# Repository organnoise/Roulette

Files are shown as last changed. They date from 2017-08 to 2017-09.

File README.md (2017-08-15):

# Roulette

<p align="center">
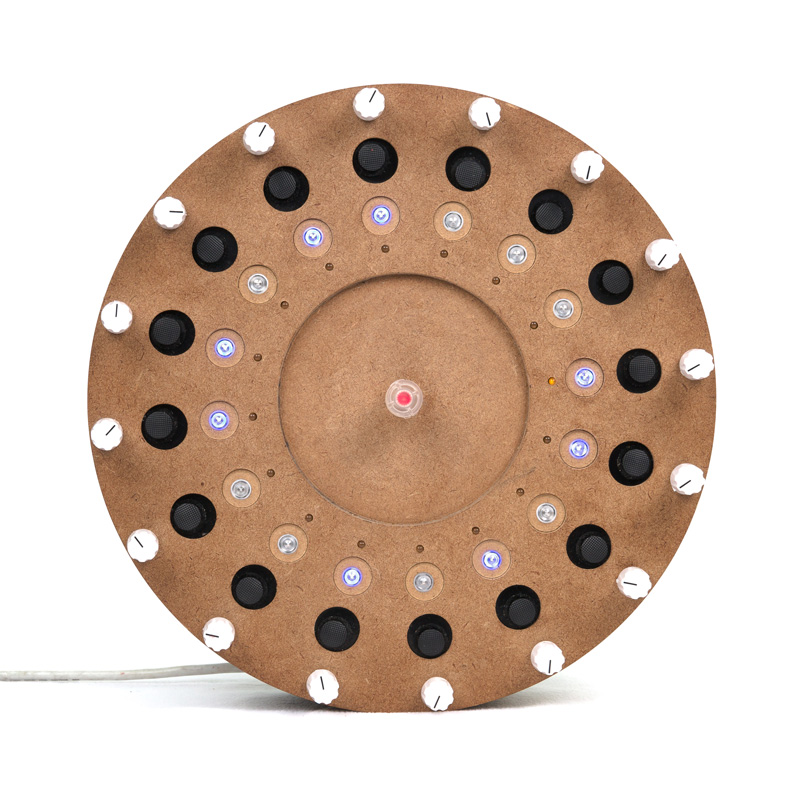
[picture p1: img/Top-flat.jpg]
  
</p>

Roulette is a generative sequencer that uses probability algorithms to create rhythmically varied drum patterns. Compositionally the intent of Roulette is to enable its user to program drum patterns in a dynamic fashion, as opposed to the static nature of typical sequential composition. From the initial design of a rhythm, varied patterns are emitted outlining a principal musical form

## CAD
CAD files for 3D printing and CNC-ing

## Arduino 
Arduino code for Teeny++ 2.0

## Eagle

Designs for both the module and the shield pcbs.

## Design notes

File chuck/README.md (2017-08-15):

# Chuck Code
<p align="center">
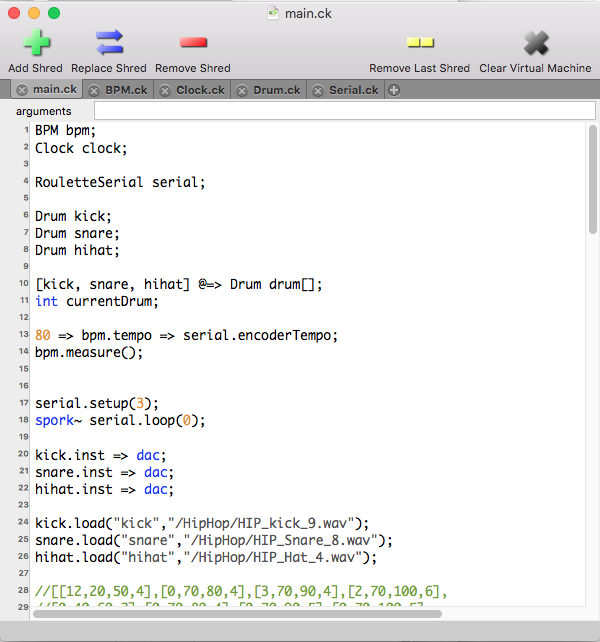
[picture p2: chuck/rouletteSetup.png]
  
</p>

Add all classes in picture above, most use BPM as a dependency so add that first.

```main.ck``` is an example of how to use the chuck code, specifically the ```Drum.ck``` class. 

## Drum.ck
```load(string OSCSendName,string pathToAudio)```

```play(float volume)```

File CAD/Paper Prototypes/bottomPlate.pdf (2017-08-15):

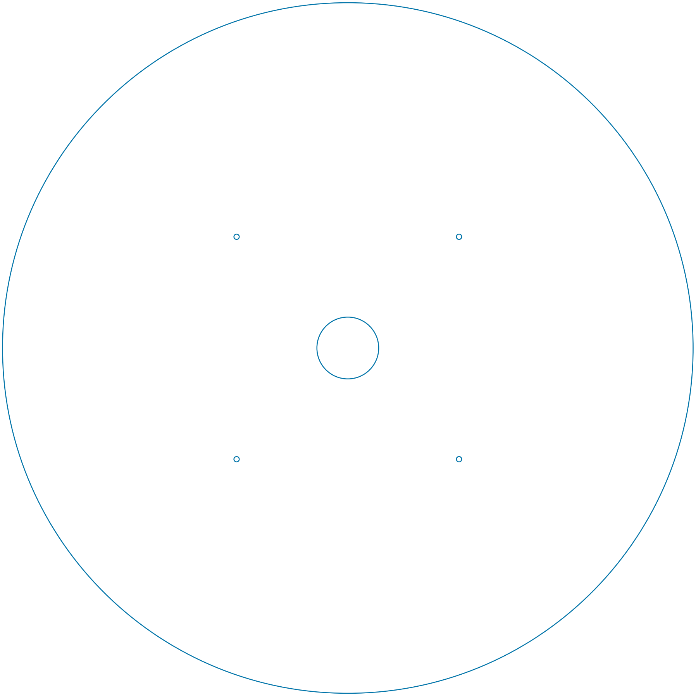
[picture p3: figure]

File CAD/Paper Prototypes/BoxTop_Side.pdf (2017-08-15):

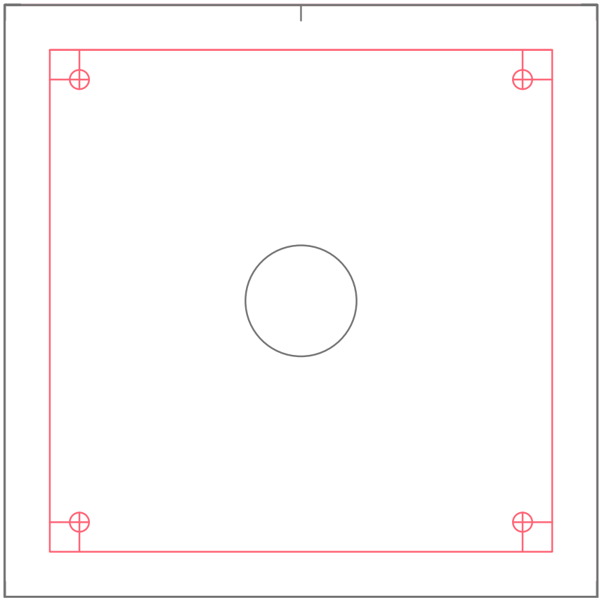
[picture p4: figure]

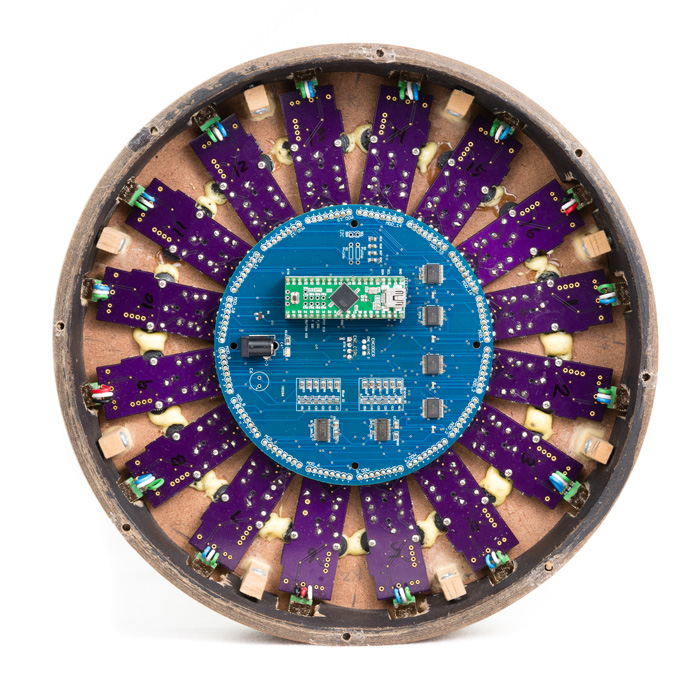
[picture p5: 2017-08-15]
img/Bottom-flat.jpg

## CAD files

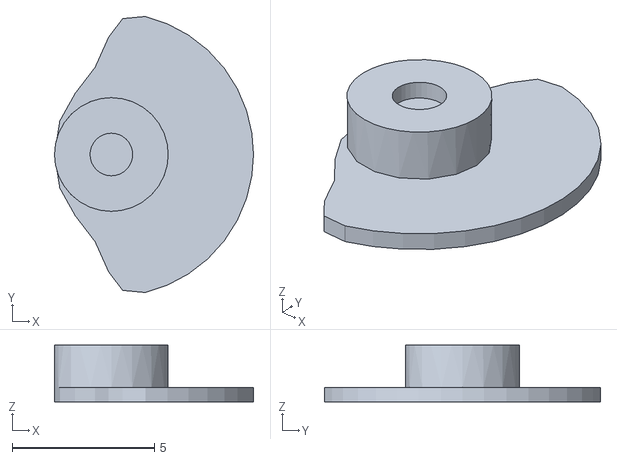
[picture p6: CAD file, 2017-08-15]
CAD/Miniature Tools/boardStop2.stl
7.00 x 9.71 x 2.00

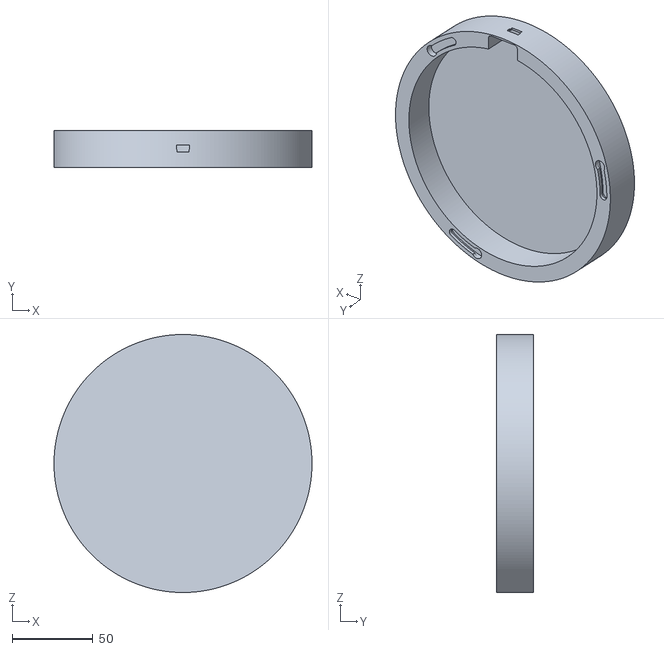
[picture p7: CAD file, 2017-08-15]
CAD/Stand/Ring1.3.stl
160.0 x 23.0 x 160.0

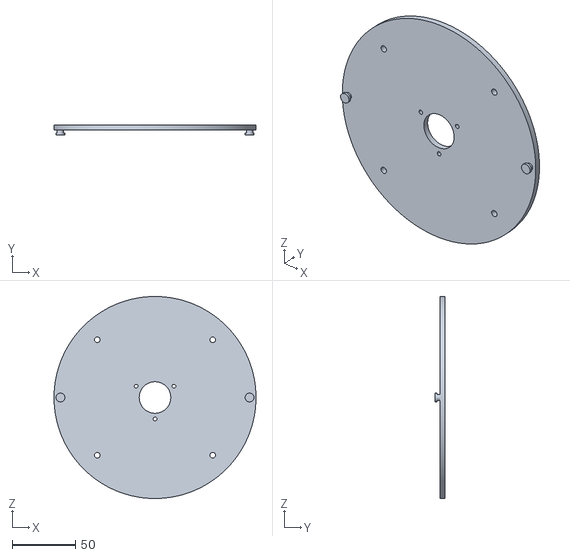
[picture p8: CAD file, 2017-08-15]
CAD/Stand/Cap.stl
160.0 x 8.00 x 160.0

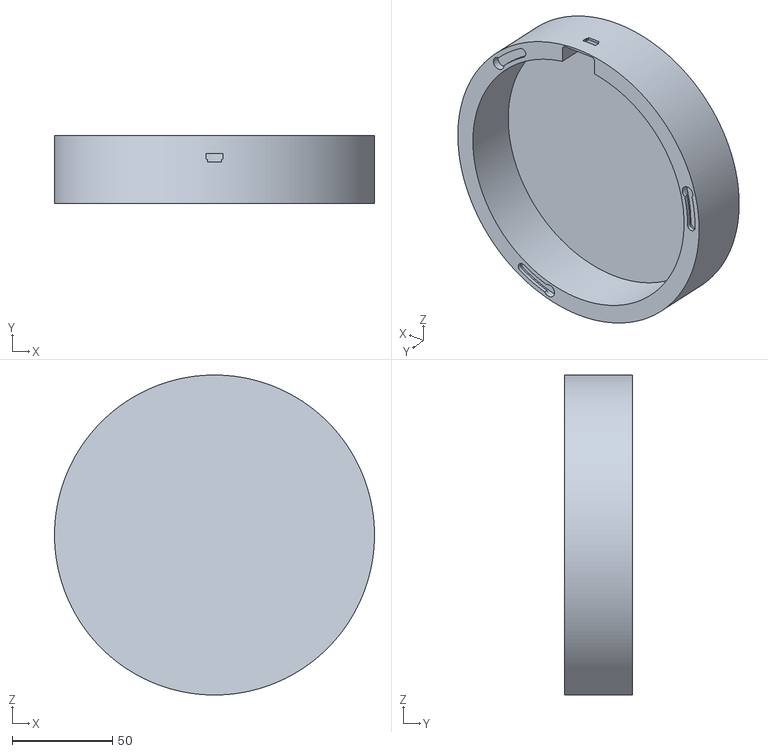
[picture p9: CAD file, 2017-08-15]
CAD/Stand/Ring1.2.stl
160.0 x 34.0 x 160.0

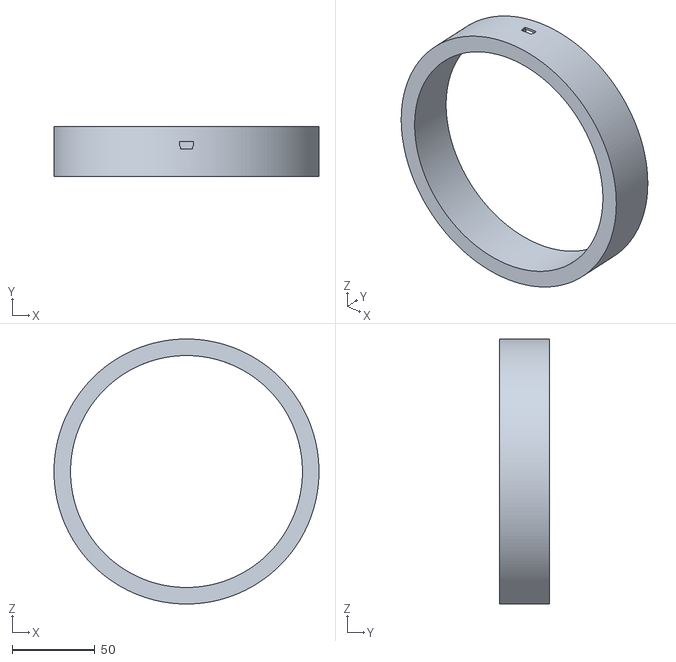
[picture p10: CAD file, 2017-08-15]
CAD/Stand/Ring1.1.stl
160.0 x 30.0 x 160.0

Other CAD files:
CAD/Stand/Cap1.2.stl
CAD/Stand/Ring.stl
CAD/Miniature Tools/boardStop.3dm
CAD/RouletteBody.3dm

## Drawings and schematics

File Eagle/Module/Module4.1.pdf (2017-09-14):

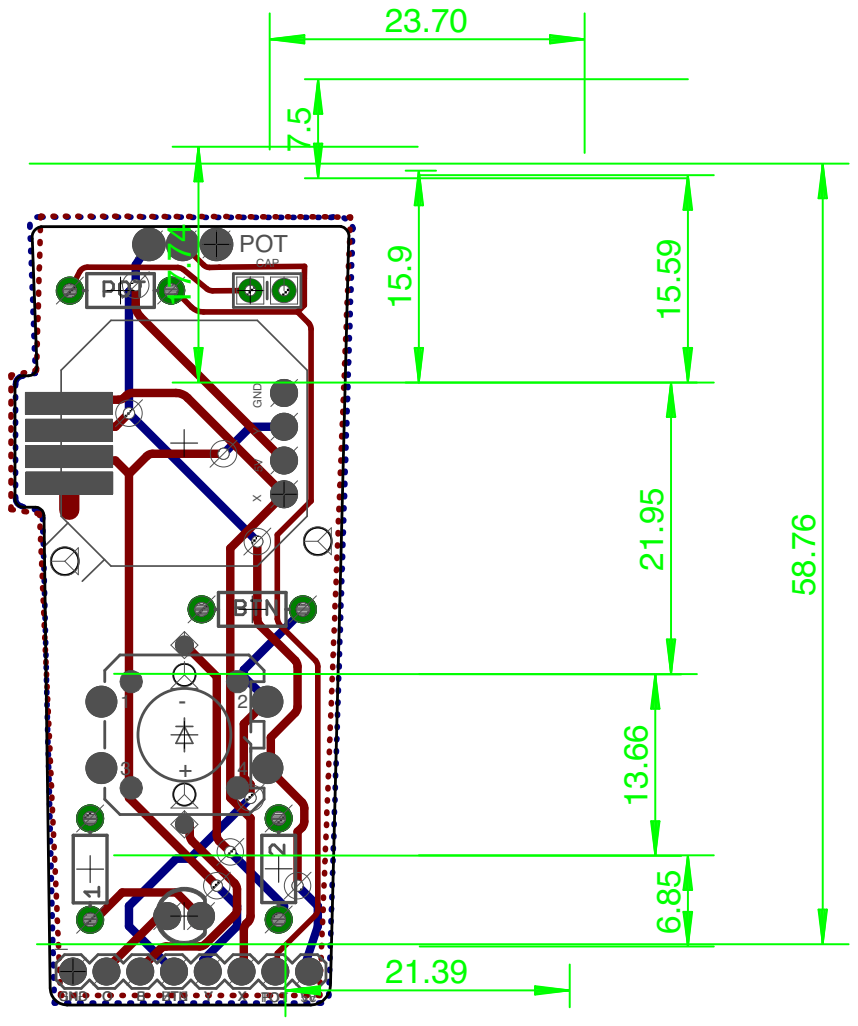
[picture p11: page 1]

DNG O B NTB Y X T OP V5 GND Y X 5V 1 2 3 + 4 - GND O B BTN Y X POT 5V _ CAP POT 13.66 21.95 15.59 23.70 6.85 21.39 7.5 15.9 17.74 58.76

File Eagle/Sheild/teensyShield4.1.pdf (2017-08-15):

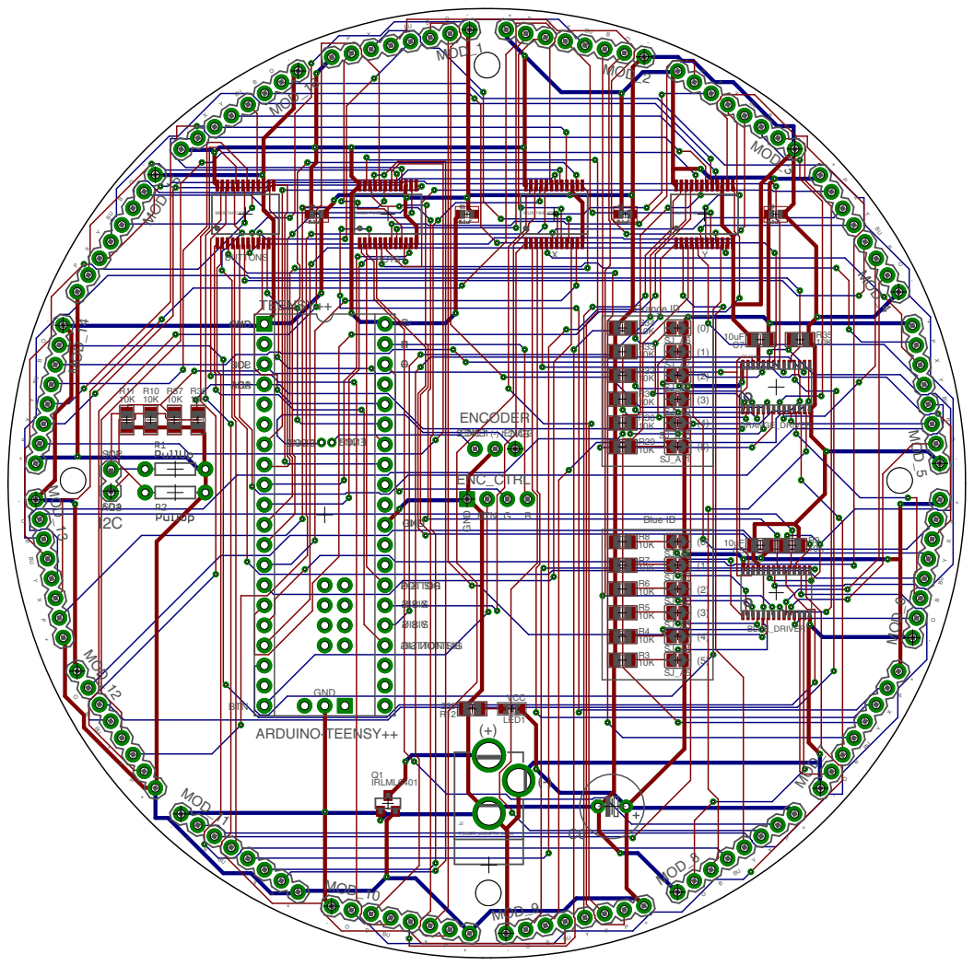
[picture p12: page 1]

TEENSY++

Orange ID
R34 | (0) (1) | R35

R11 R10 | SDA | R31 10K | SJ_A8 | (3)

GND | | Blue ID

10K | (1) | PCA9685

POT SIG X SIG | SJ_A1 | (2)

J2 POWER_JACKPTH_LOCK

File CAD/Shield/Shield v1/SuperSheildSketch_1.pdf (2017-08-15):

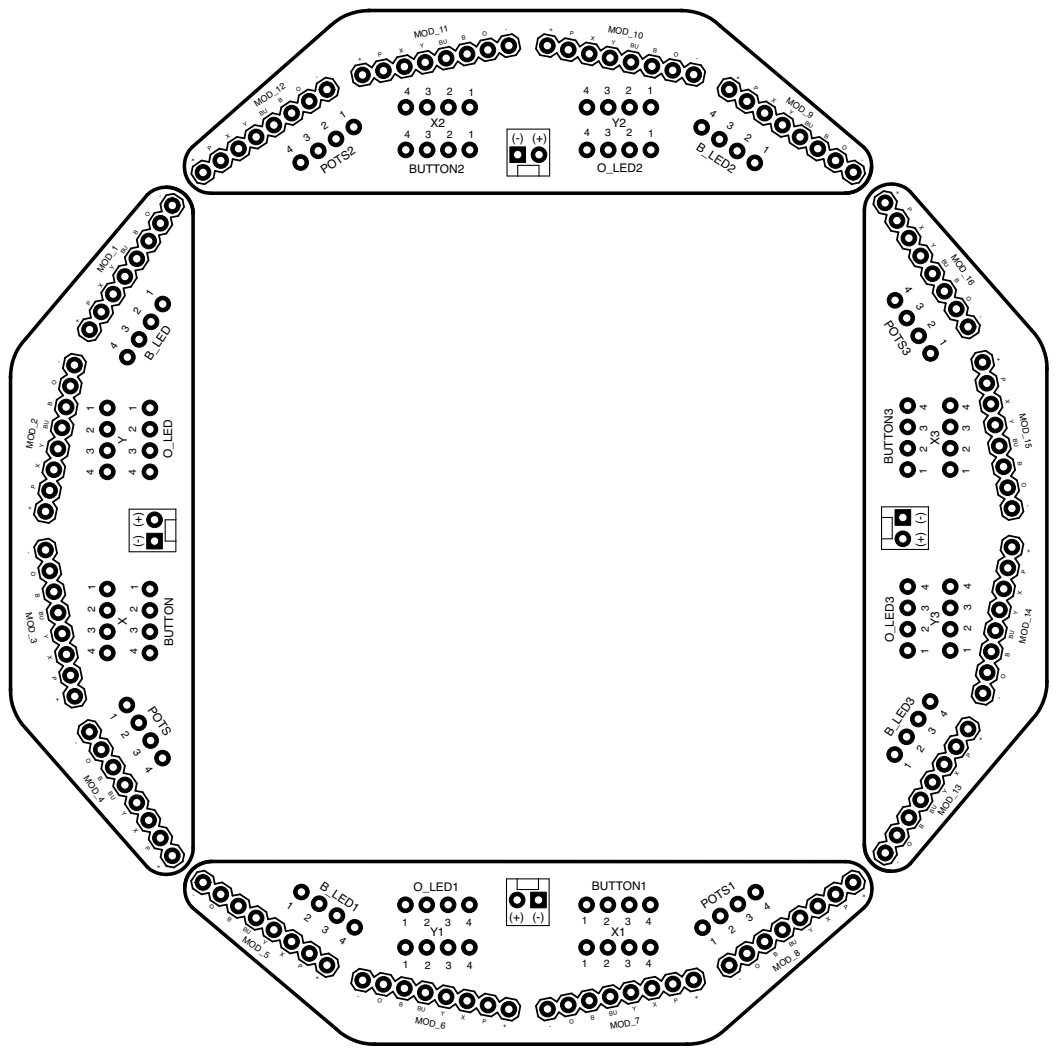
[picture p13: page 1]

(-) (+) 1 2 3 4 1 2 3 4 1 2 3 4 1 2 3 4 1 2 3 4 1 2 3 4 X Y P BU O B + - X Y P BU O B + - X Y P BU O B + - X Y P BU O B + - (+) (-) 1 2 3 4 1 2 3 4 1 2 3 4 1 2 3 4 1 2 3 4 1 2 3 4 X Y P BU O B + - X Y P BU O B + - X Y P BU O B + - X Y P BU O B + - (-) (+) 4 3 2 1 4 3 2 1 4 3 2 1 4 3 2 1 1 2 3 4 1 2 3 4 X Y P BU O B + - X Y P BU O B + - X Y P BU O B + - X Y P BU O B + - (-) (+) 1 2 3 4 1 2 3 4 1 2 3 4 1 2 3 4 1 2 3 4 1 2 3 4 X Y P BU O B + - X Y P BU O B + - X Y P BU O B + - X Y P BU O B + - B_LED BUTTON MOD_1 MOD_2 MOD_3 MOD_4 O_LED POTS X Y B_LED1 BUTTON1 MOD_5 MOD_6 MOD_7 MOD_8 O_LED1 POTS1 Y1 X1 B_LED BUTTON2 2 MOD_9 MOD MOD_10 _11 MOD_12 PO O_LED2 TS2 X2 Y2 B_LED3 BUTTON3 MOD_13 MOD_14 MOD_15 MOD_16 O_LED3 POTS3 X3 Y3

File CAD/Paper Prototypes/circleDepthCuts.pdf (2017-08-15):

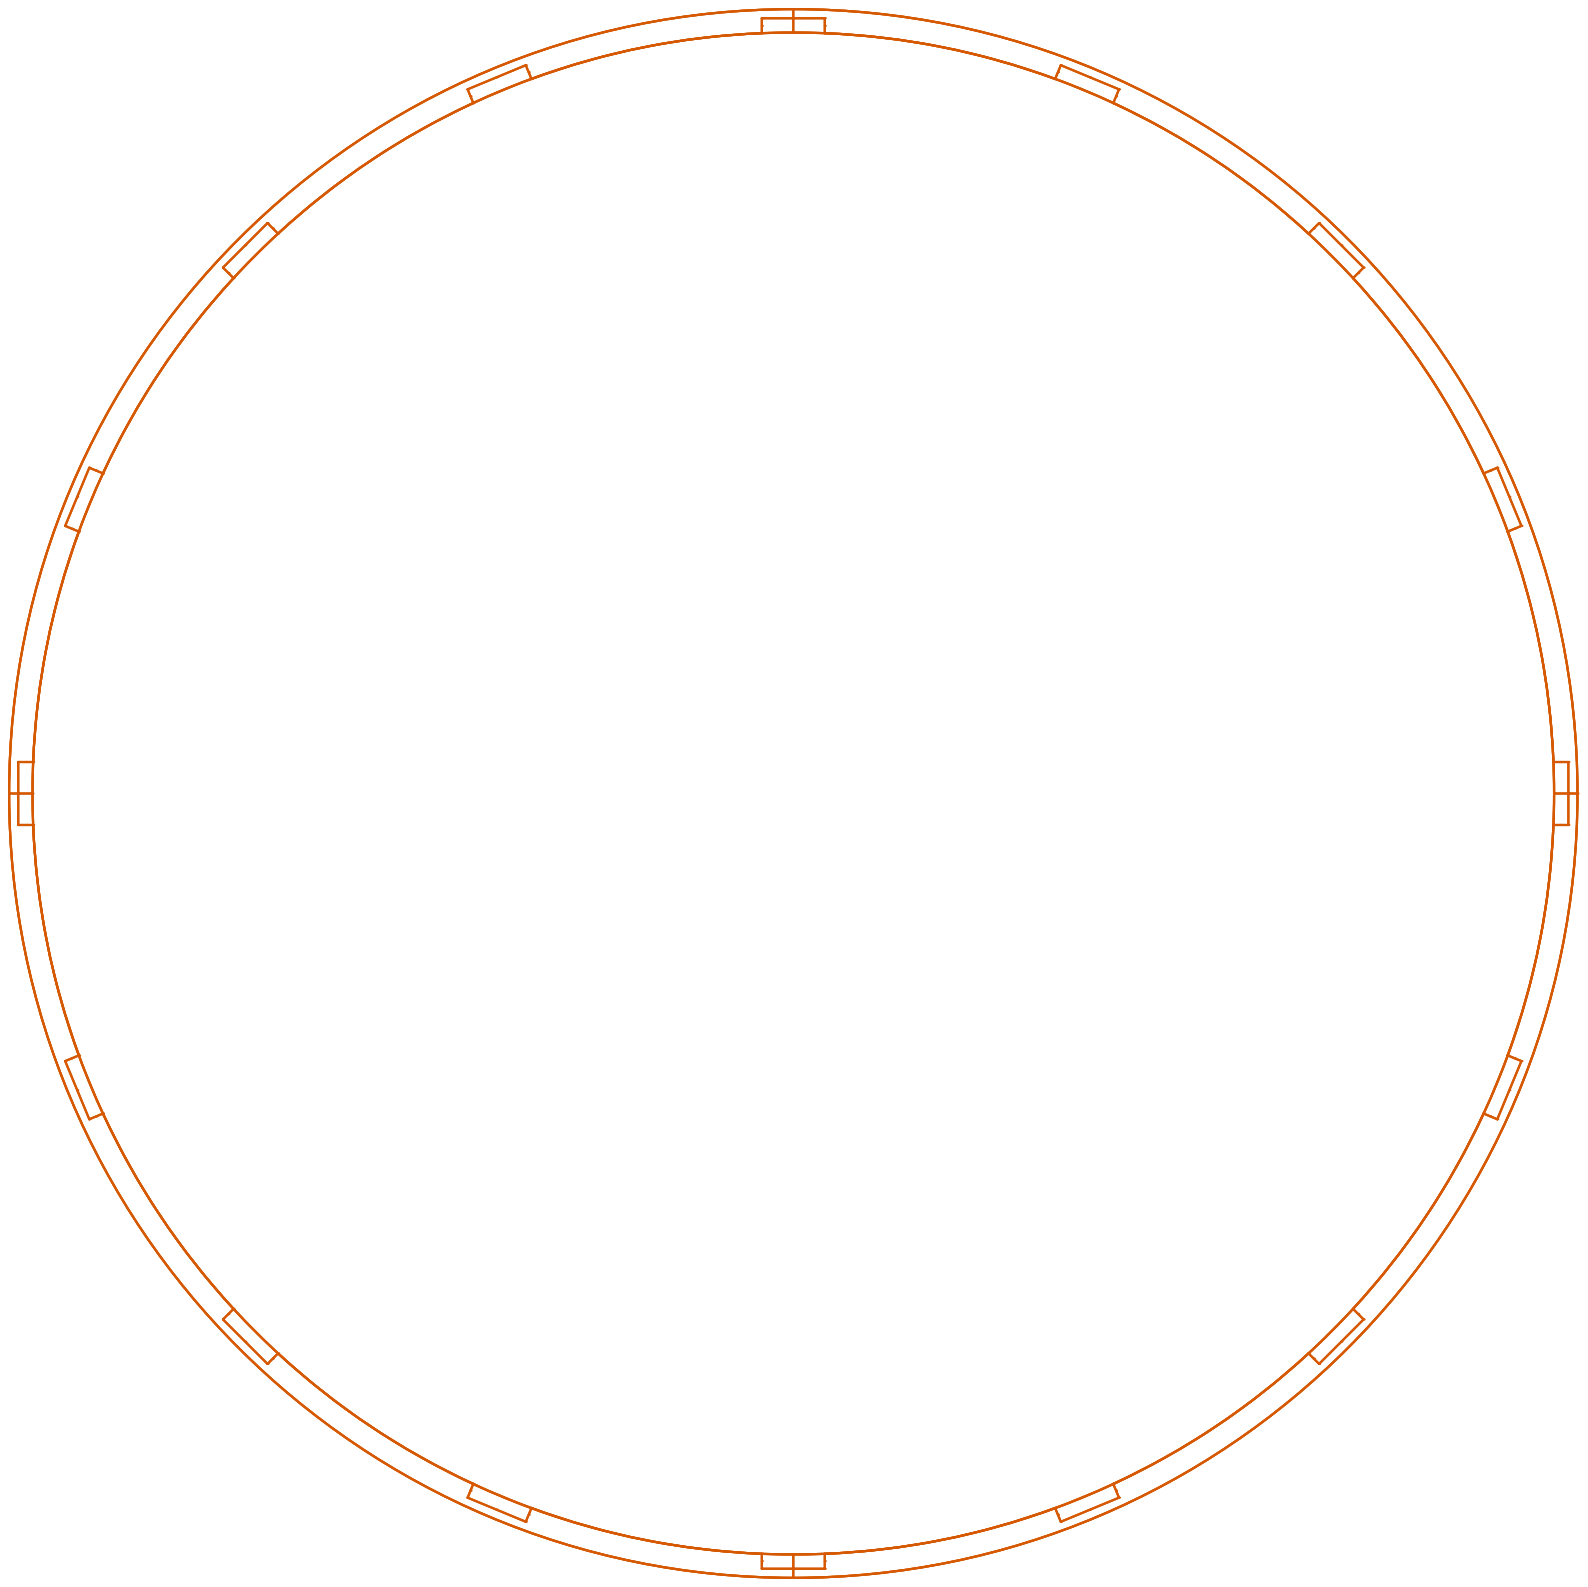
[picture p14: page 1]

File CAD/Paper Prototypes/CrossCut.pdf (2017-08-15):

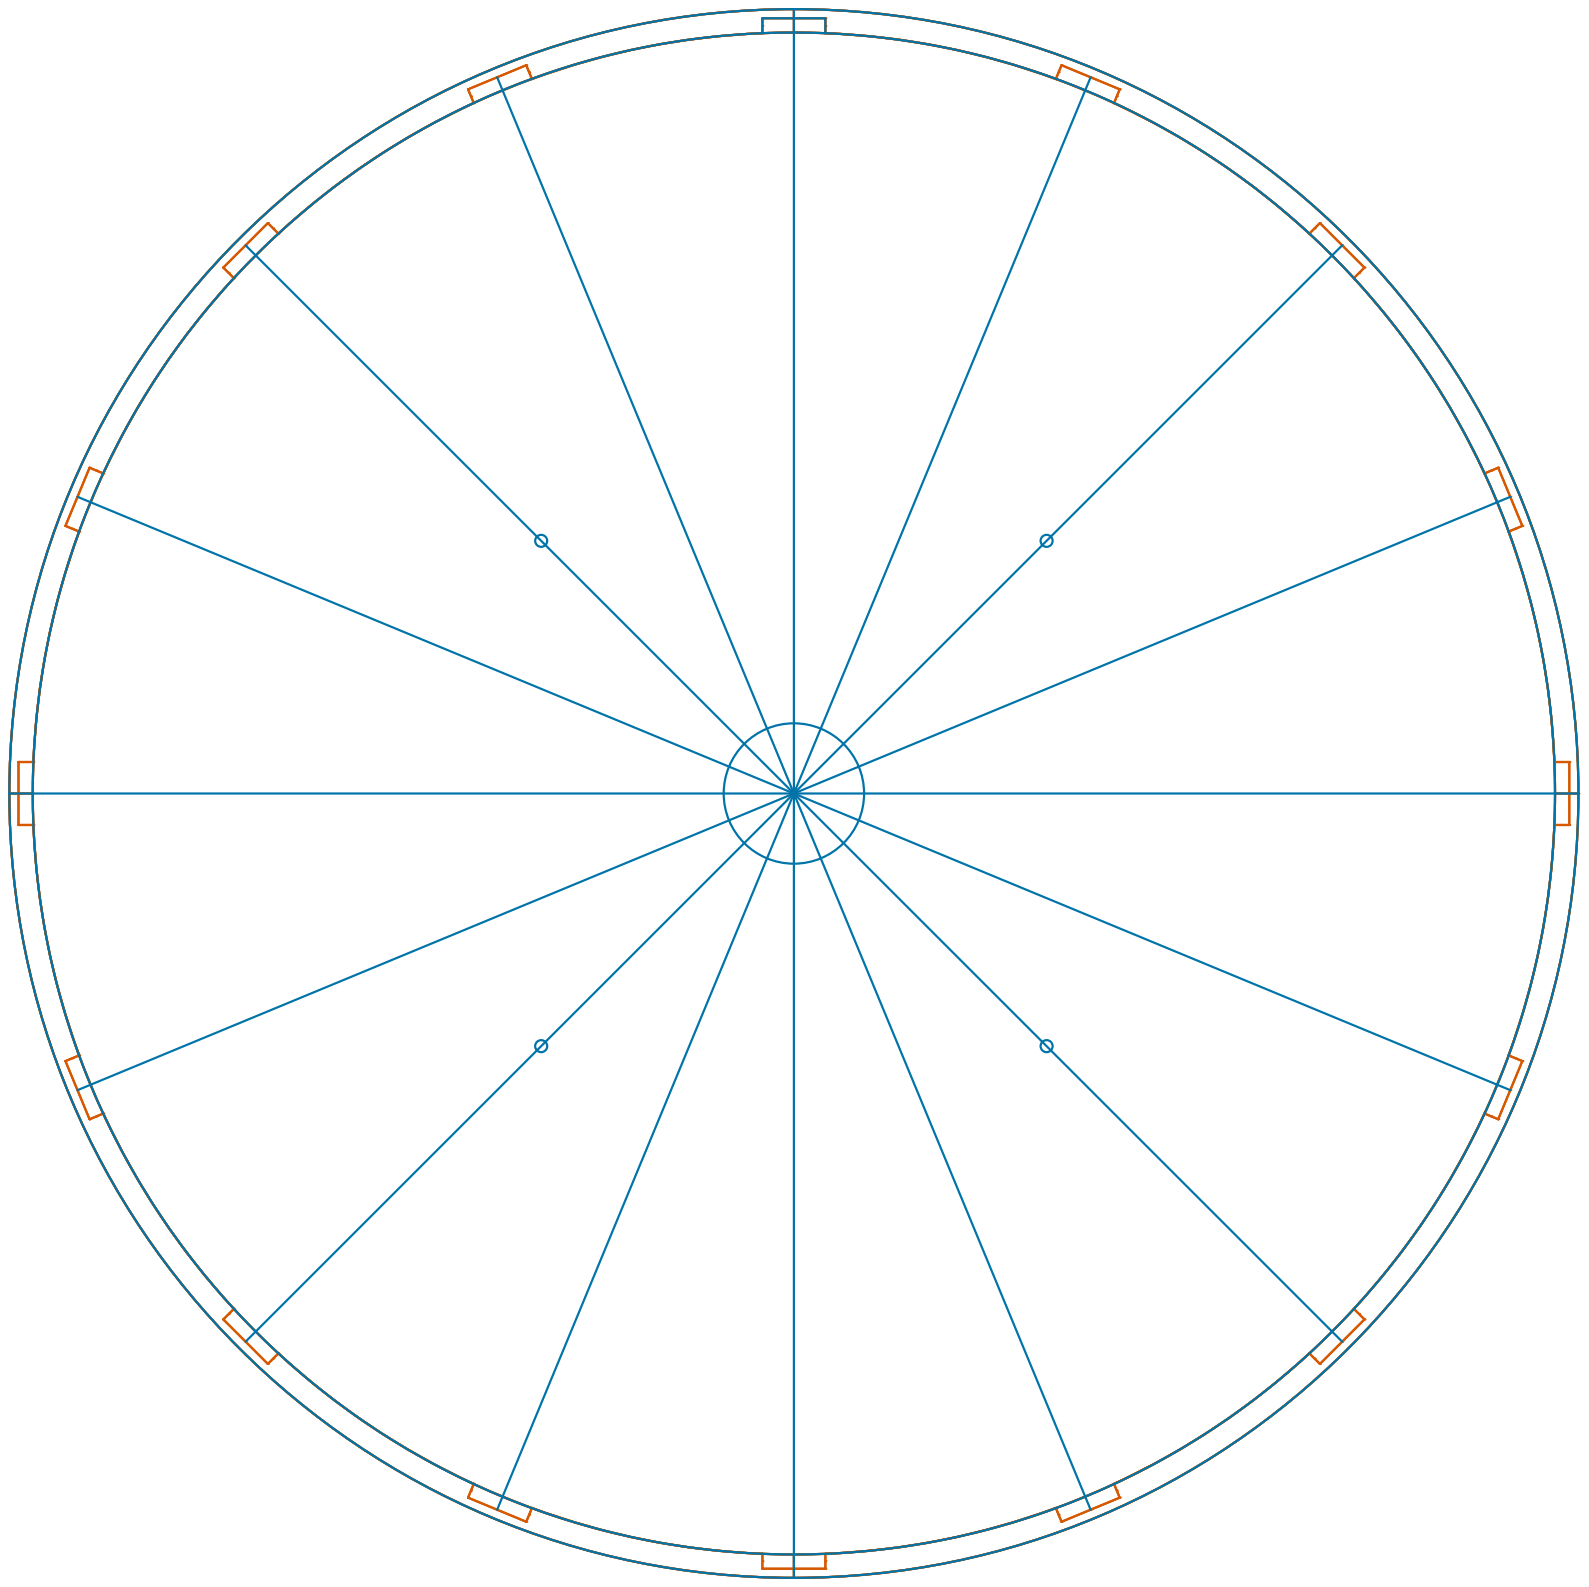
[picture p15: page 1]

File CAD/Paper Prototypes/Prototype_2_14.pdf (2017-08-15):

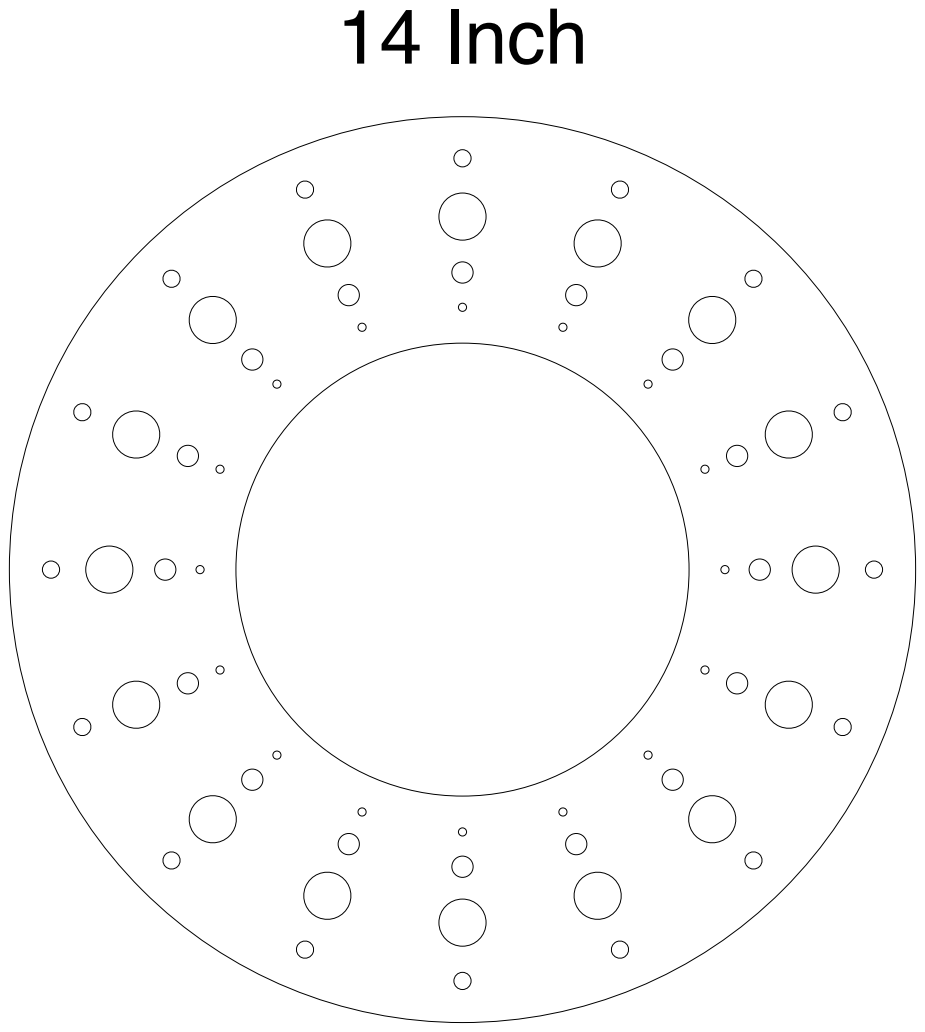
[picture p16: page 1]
14 Inch

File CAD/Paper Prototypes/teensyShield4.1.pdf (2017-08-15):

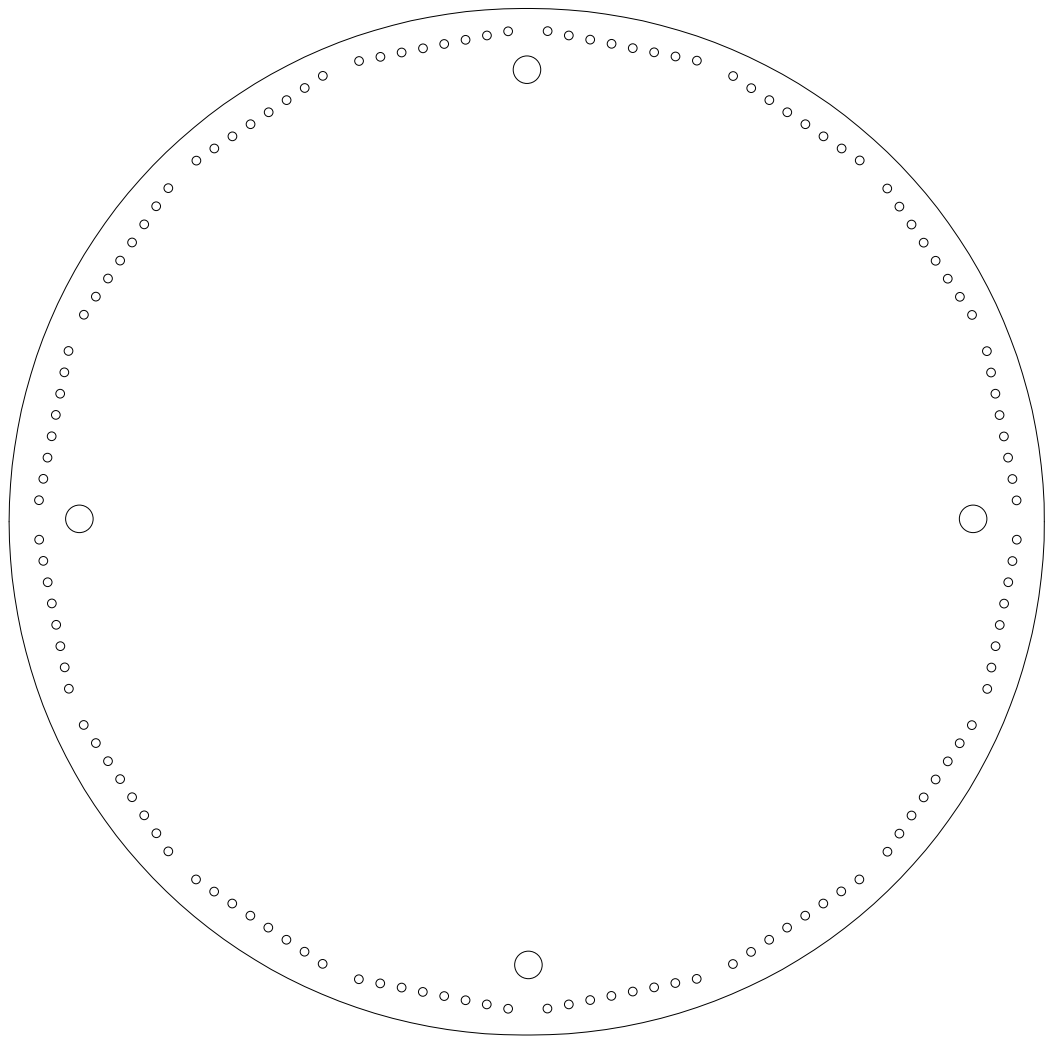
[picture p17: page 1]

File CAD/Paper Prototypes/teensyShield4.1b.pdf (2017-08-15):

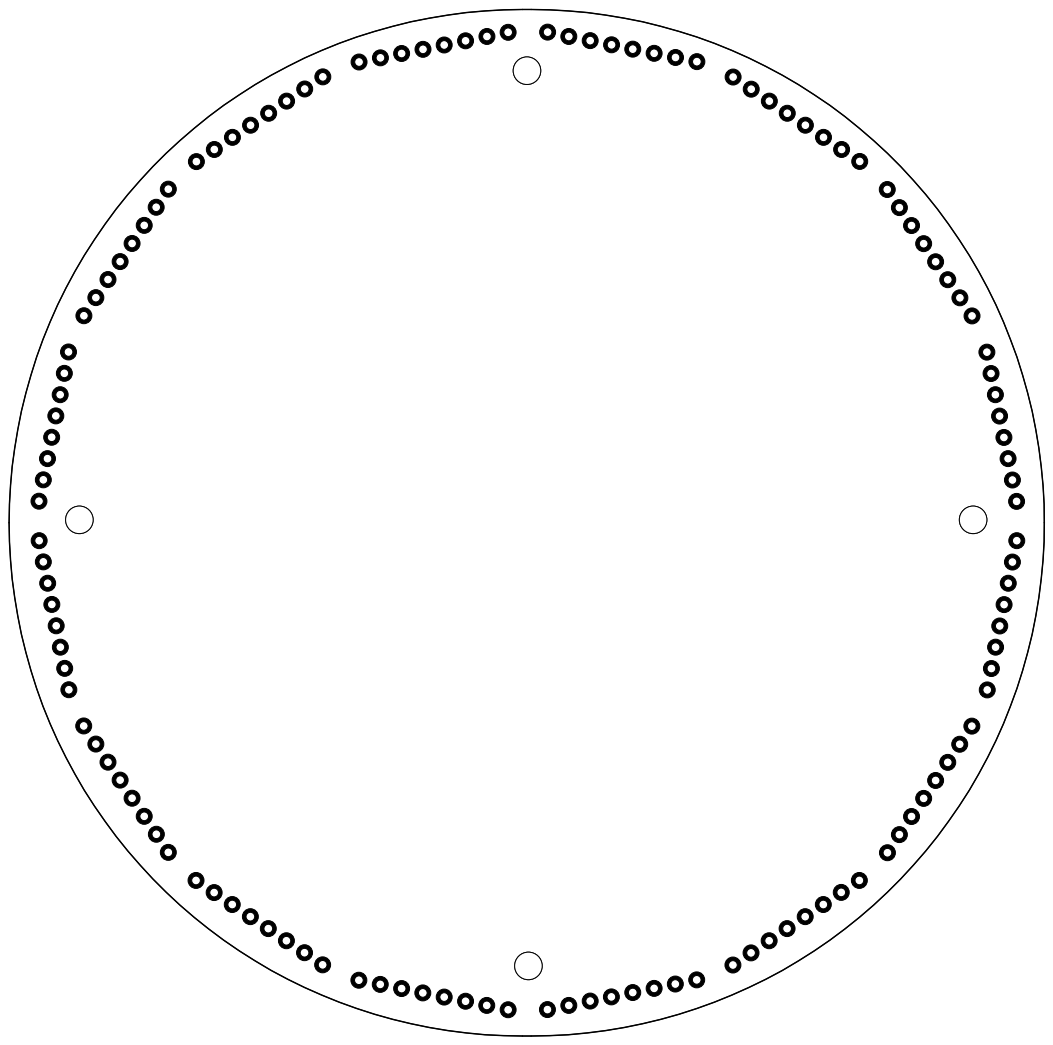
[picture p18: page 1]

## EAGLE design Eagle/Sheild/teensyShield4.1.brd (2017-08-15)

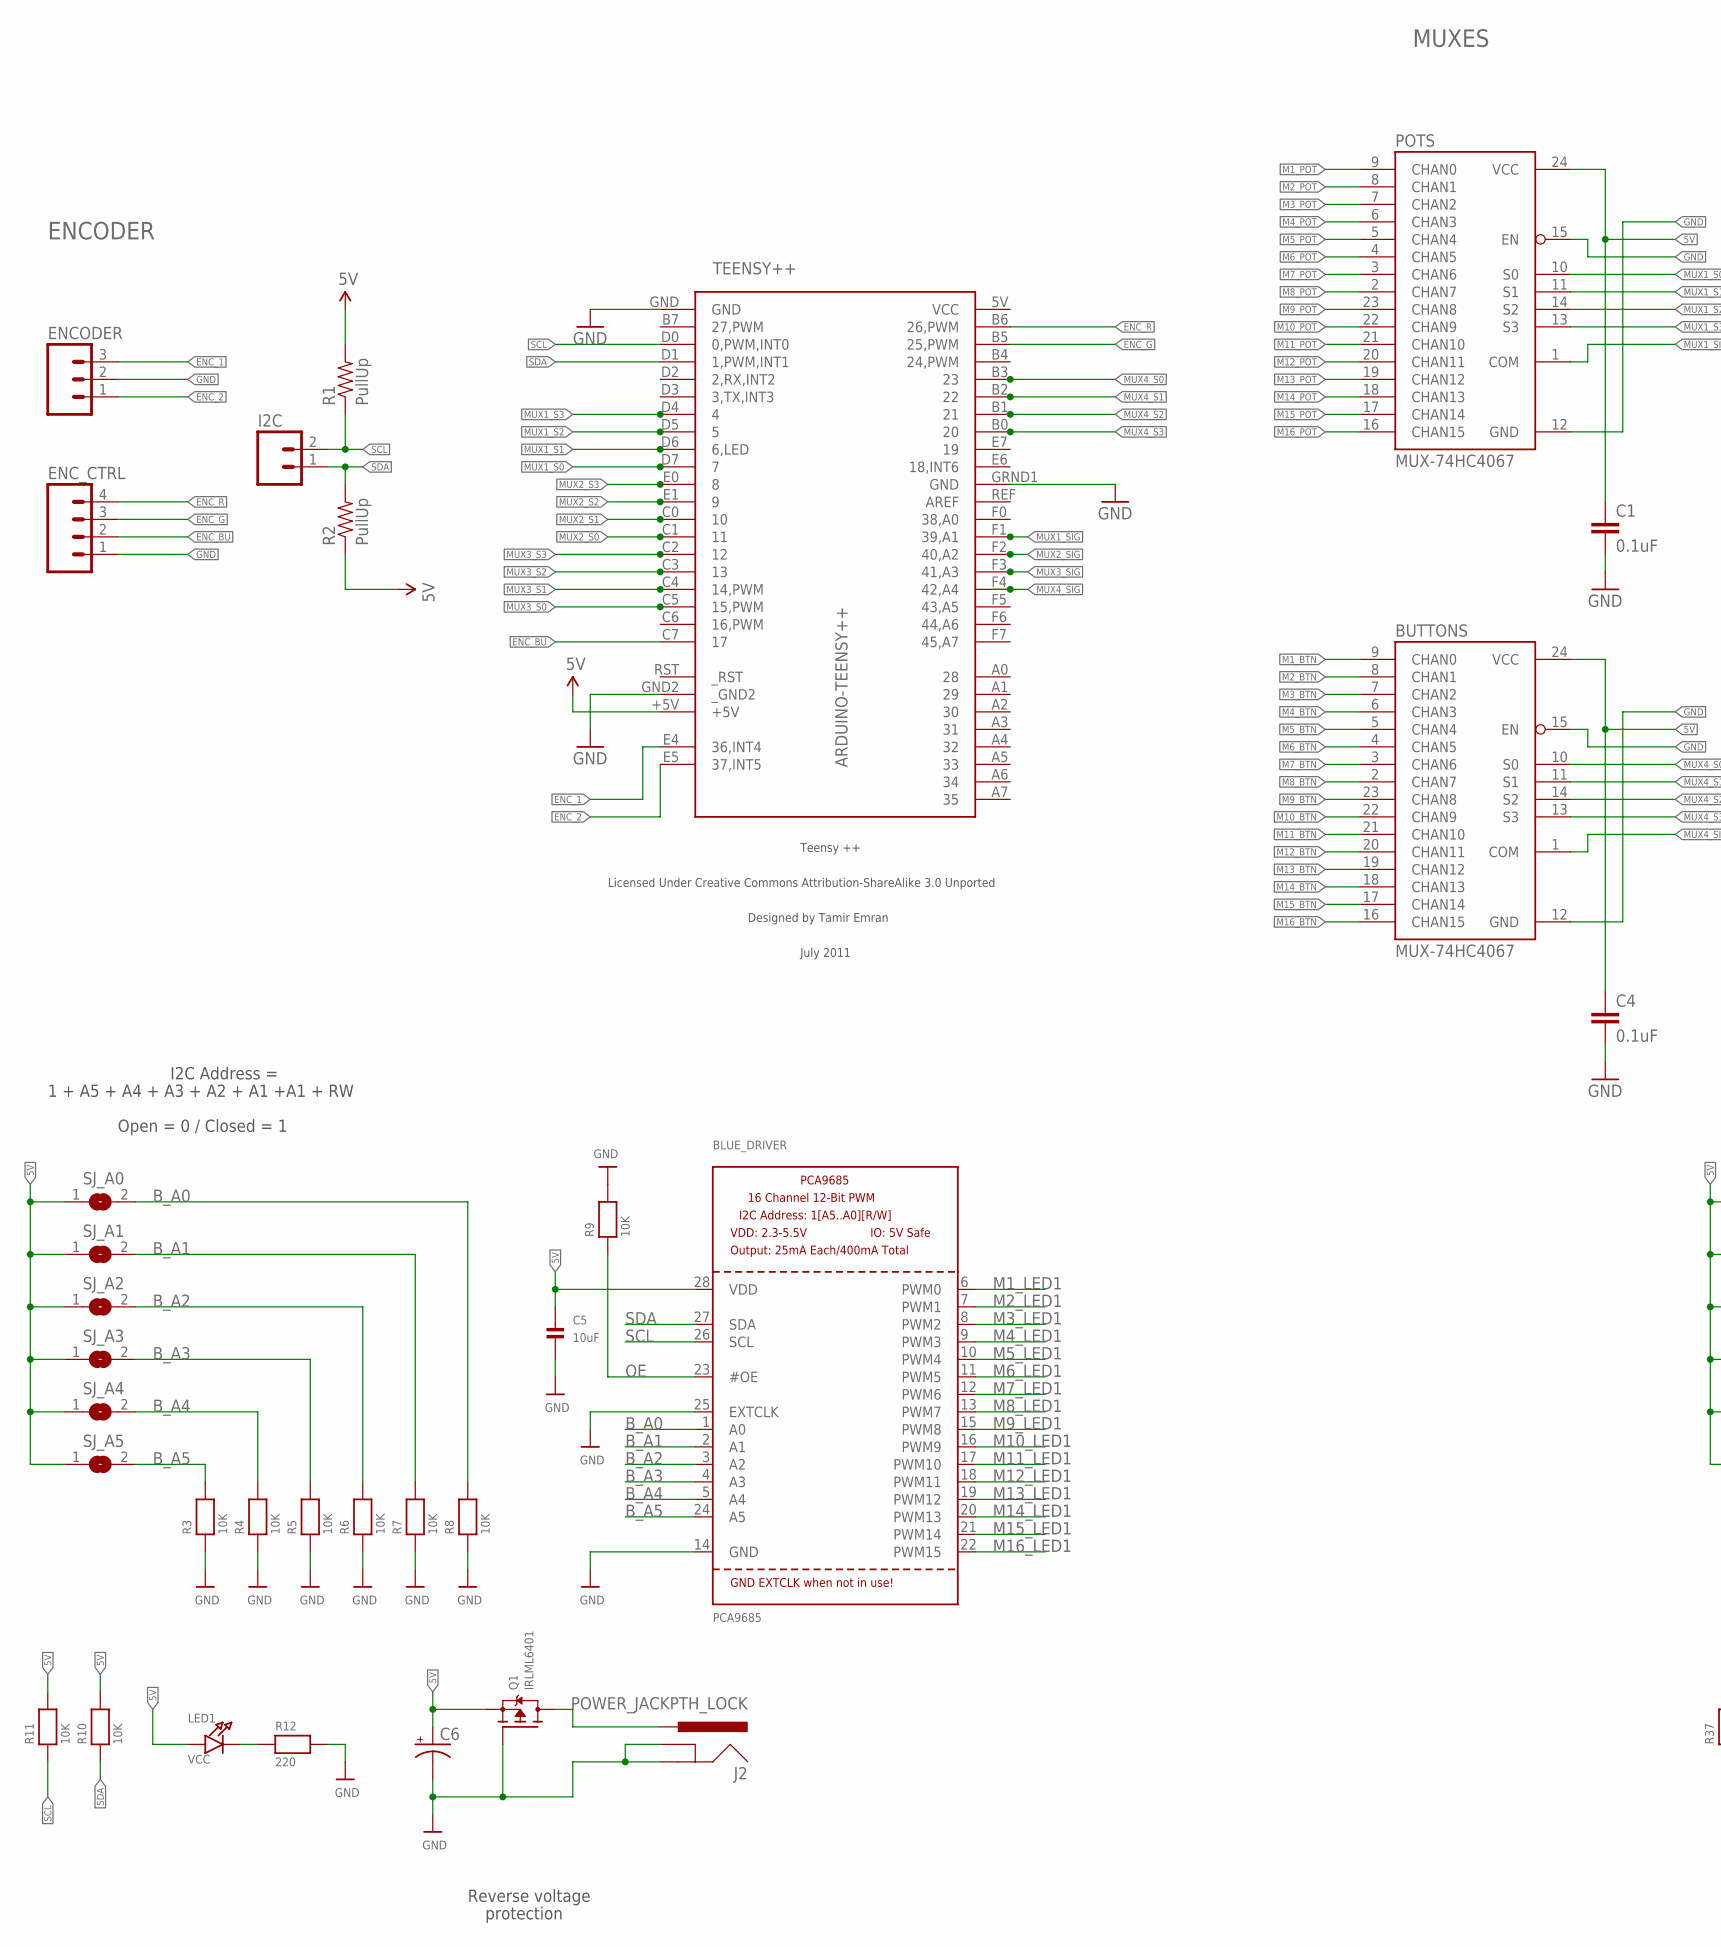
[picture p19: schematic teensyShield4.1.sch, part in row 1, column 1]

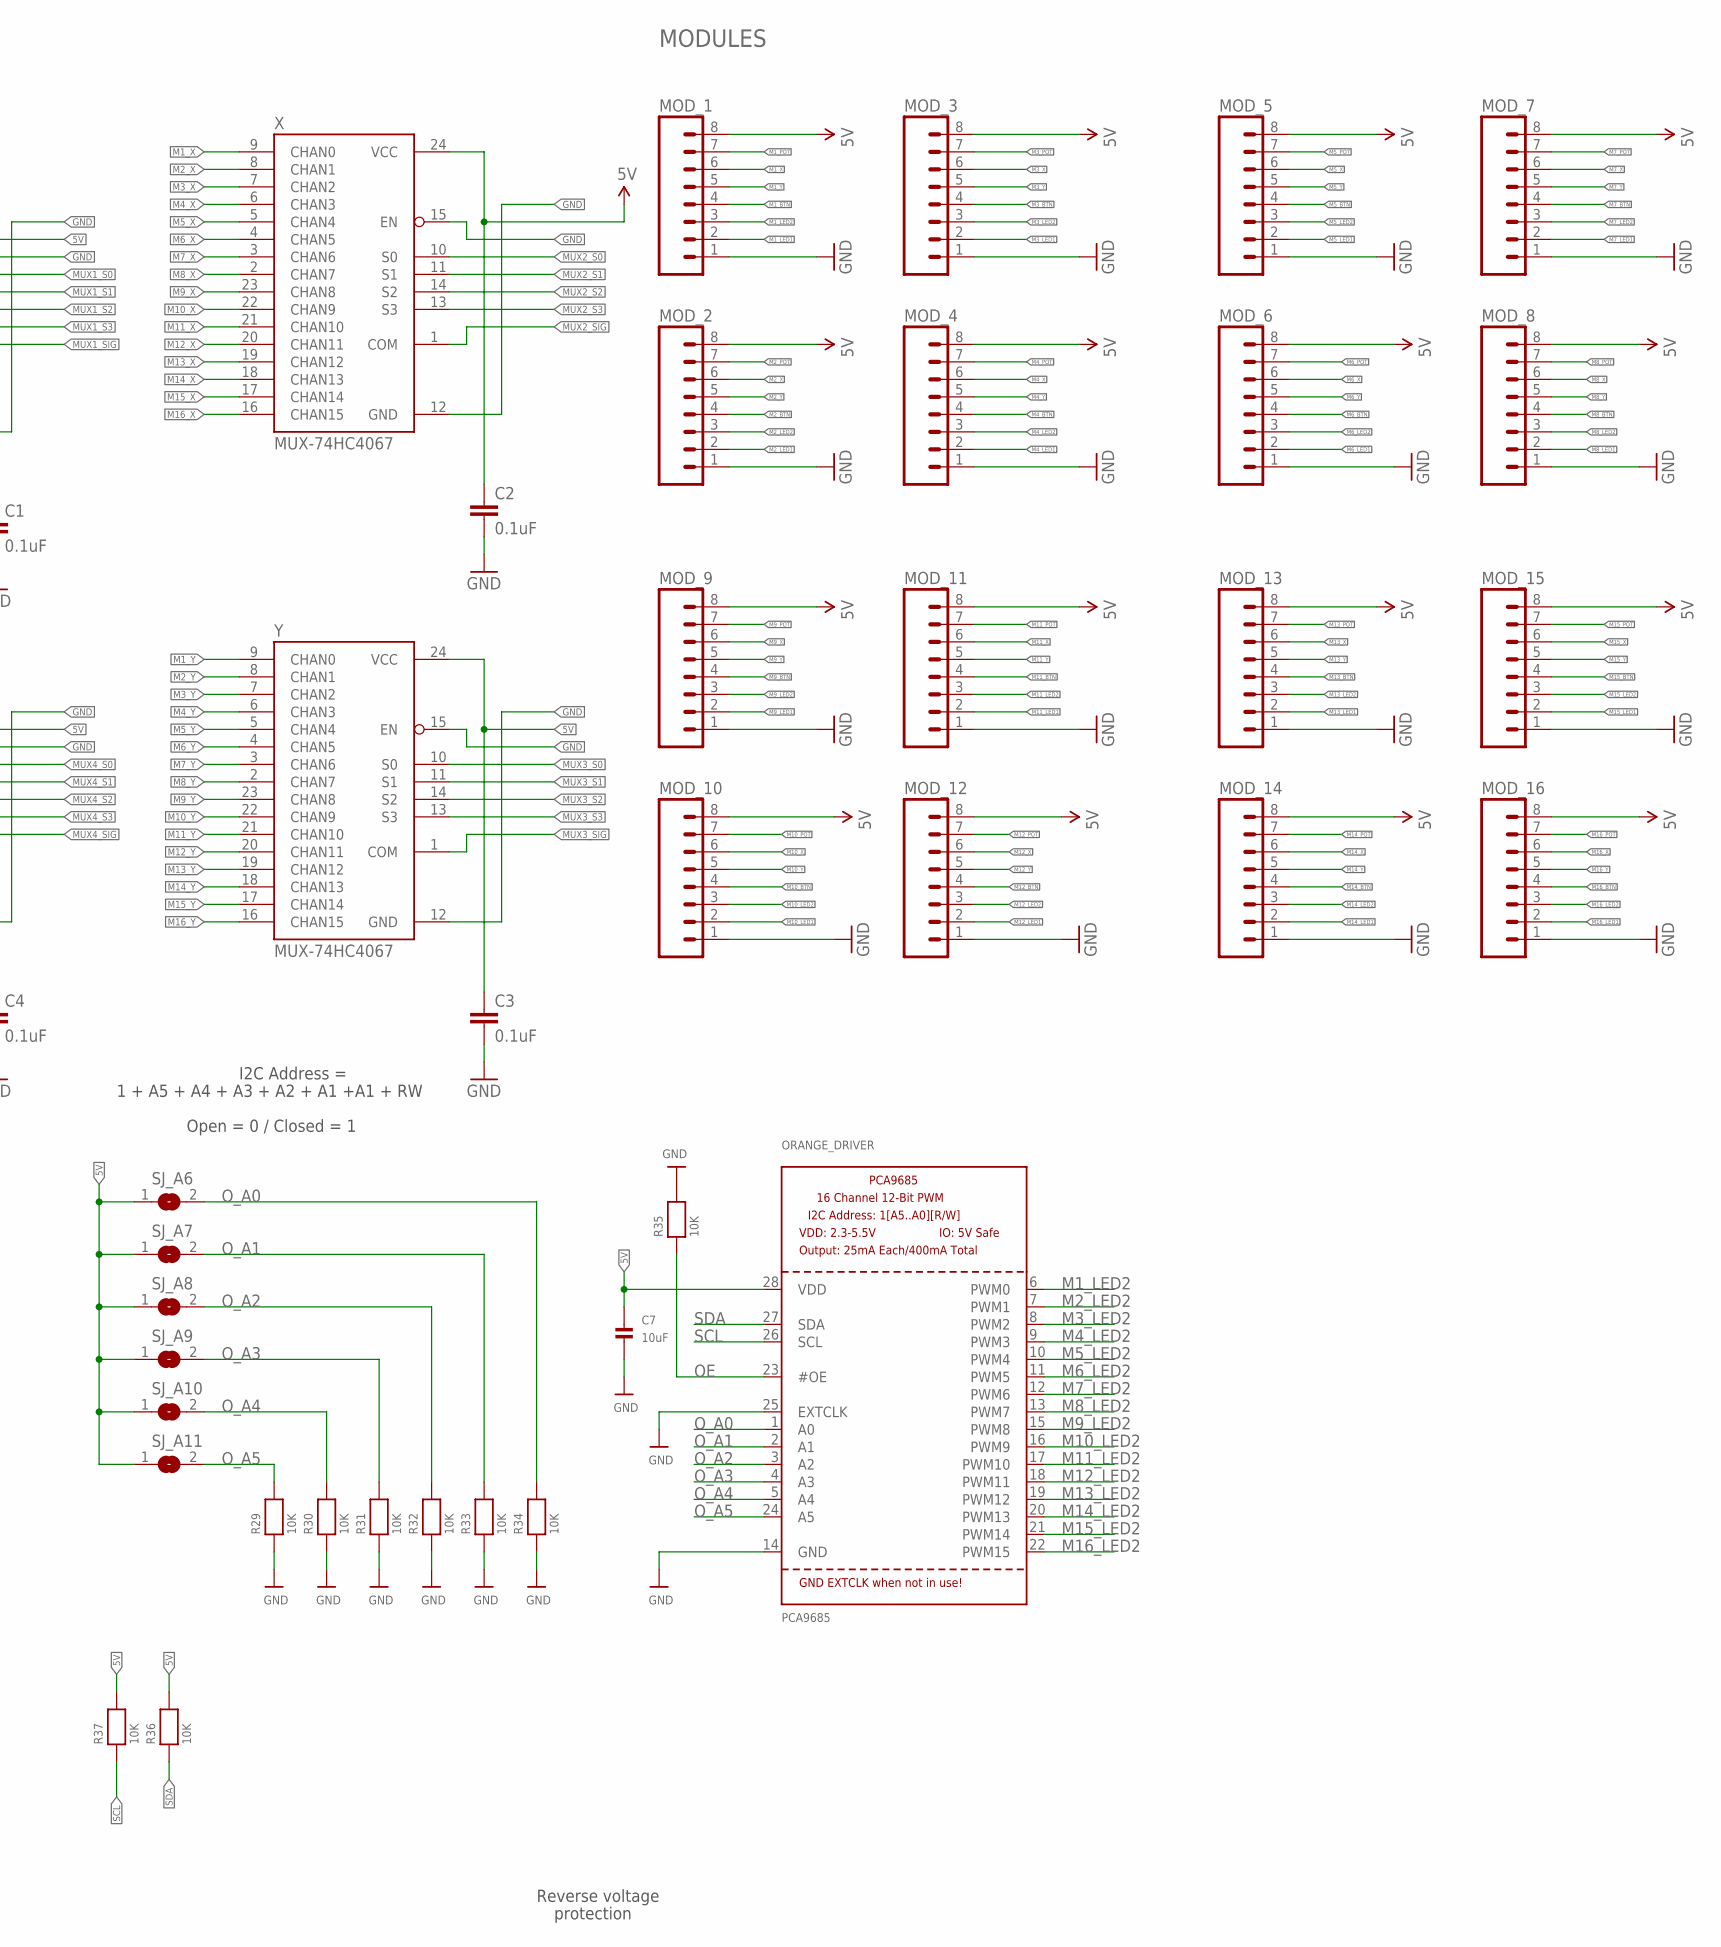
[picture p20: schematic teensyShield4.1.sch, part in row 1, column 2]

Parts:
BLUE_DRIVER: PCA9685; TSSOP28
BUTTONS: MUX-74HC4067; SSOP24
C1, C2, C3, C4: 0.1uF; 0603
C5, C7: 10uF; 0805
C6: CPOL-USE3.5-8; E3,5-8
ENCODER: M031X03_NO_SILK; 1X03_NO_SILK
ENC_CTRL: M041X04_NO_SILK; 1X04_NO_SILK
I2C: M02LOCK; 1X02_LOCK
J2: POWER_JACKPTH_LOCK; POWER_JACK_PTH_LOCK
LED1: VCC; CHIPLED_0805
MOD_1, MOD_2, MOD_3, MOD_4, MOD_5, MOD_6, MOD_7, MOD_8, MOD_9, MOD_10, MOD_11, MOD_12, MOD_13, MOD_14, MOD_15, MOD_16: M08; 1X08_ROUND
ORANGE_DRIVER: PCA9685; TSSOP28
POTS: MUX-74HC4067; SSOP24
Q1: IRLML6401; SOT23-WIDE
R1, R2: PullUp; AXIAL-0.3
R3, R4, R5, R6, R7, R8, R9, R10, R11, R29, R30, R31, R32, R33, R34, R35, R36, R37: 10K; 0805
R12: 220; 0805
SJ_A0, SJ_A1, SJ_A2, SJ_A3, SJ_A4, SJ_A5, SJ_A6, SJ_A7, SJ_A8, SJ_A9, SJ_A10, SJ_A11: SOLDERJUMPERREFLOW_NOPASTE; SOLDERJUMPER_REFLOW_NOPASTE
TEENSY++: ARDUINO-TEENSY++; TEENSY++
X: MUX-74HC4067; SSOP24
Y: MUX-74HC4067; SSOP24

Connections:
5V: BLUE_DRIVER.28 (VDD), BUTTONS.24 (VCC), C1.1, C2.1, C3.1, C4.1, C5.1, C6.+, C7.1, LED1.A, MOD_1.8, MOD_2.8, MOD_3.8, MOD_4.8, MOD_5.8, MOD_6.8, MOD_7.8, MOD_8.8, MOD_9.8, MOD_10.8, MOD_11.8, MOD_12.8, MOD_13.8, MOD_14.8, MOD_15.8, MOD_16.8, ORANGE_DRIVER.28 (VDD), POTS.24 (VCC), Q1.2 (S), R1.P$2 (2), R2.P$1 (1), R10.2, R11.2, R36.2, R37.2, SJ_A0.1, SJ_A1.1, SJ_A2.1, SJ_A3.1, SJ_A4.1, SJ_A5.1, SJ_A6.1, SJ_A7.1, SJ_A8.1, SJ_A9.1, SJ_A10.1, SJ_A11.1, TEENSY++.+5V, X.24 (VCC), Y.24 (VCC)
B_A0: BLUE_DRIVER.1 (A0), R8.2, SJ_A0.2
B_A1: BLUE_DRIVER.2 (A1), R7.2, SJ_A1.2
B_A2: BLUE_DRIVER.3 (A2), R6.2, SJ_A2.2
B_A3: BLUE_DRIVER.4 (A3), R5.2, SJ_A3.2
B_A4: BLUE_DRIVER.5 (A4), R4.2, SJ_A4.2
B_A5: BLUE_DRIVER.24 (A5), R3.2, SJ_A5.2
ENC_1: ENCODER.3, TEENSY++.E4 (36,INT4)
ENC_2: ENCODER.1, TEENSY++.E5 (37,INT5)
ENC_BU: ENC_CTRL.2, TEENSY++.C7 (17)
ENC_G: ENC_CTRL.3, TEENSY++.B5 (25,PWM)
ENC_R: ENC_CTRL.4, TEENSY++.B6 (26,PWM)
GND: BLUE_DRIVER.14 (GND), BLUE_DRIVER.25 (EXTCLK), BUTTONS.12 (GND), BUTTONS.15 (EN), C1.2, C2.2, C3.2, C4.2, C5.2, C6.-, C7.2, ENCODER.2, ENC_CTRL.1, J2.GND, J2.GNDBREAK, MOD_1.1, MOD_2.1, MOD_3.1, MOD_4.1, MOD_5.1, MOD_6.1, MOD_7.1, MOD_8.1, MOD_9.1, MOD_10.1, MOD_11.1, MOD_12.1, MOD_13.1, MOD_14.1, MOD_15.1, MOD_16.1, ORANGE_DRIVER.14 (GND), ORANGE_DRIVER.25 (EXTCLK), POTS.12 (GND), POTS.15 (EN), Q1.1 (G), R3.1, R4.1, R5.1, R6.1, R7.1, R8.1, R9.2, R12.2, R29.1, R30.1, R31.1, R32.1, R33.1, R34.1, R35.2, TEENSY++.GND, TEENSY++.GND2 (_GND2), TEENSY++.GRND1 (GND), X.12 (GND), X.15 (EN), Y.12 (GND), Y.15 (EN)
M1_BTN: BUTTONS.9 (CHAN0), MOD_1.4
M1_LED1: BLUE_DRIVER.6 (PWM0), MOD_1.2
M1_LED2: MOD_1.3, ORANGE_DRIVER.6 (PWM0)
M1_POT: MOD_1.7, POTS.9 (CHAN0)
M1_X: MOD_1.6, X.9 (CHAN0)
M1_Y: MOD_1.5, Y.9 (CHAN0)
M2_BTN: BUTTONS.8 (CHAN1), MOD_2.4
M2_LED1: BLUE_DRIVER.7 (PWM1), MOD_2.2
M2_LED2: MOD_2.3, ORANGE_DRIVER.7 (PWM1)
M2_POT: MOD_2.7, POTS.8 (CHAN1)
M2_X: MOD_2.6, X.8 (CHAN1)
M2_Y: MOD_2.5, Y.8 (CHAN1)
M3_BTN: BUTTONS.7 (CHAN2), MOD_3.4
M3_LED1: BLUE_DRIVER.8 (PWM2), MOD_3.2
M3_LED2: MOD_3.3, ORANGE_DRIVER.8 (PWM2)
M3_POT: MOD_3.7, POTS.7 (CHAN2)
M3_X: MOD_3.6, X.7 (CHAN2)
M3_Y: MOD_3.5, Y.7 (CHAN2)
M4_BTN: BUTTONS.6 (CHAN3), MOD_4.4
M4_LED1: BLUE_DRIVER.9 (PWM3), MOD_4.2
M4_LED2: MOD_4.3, ORANGE_DRIVER.9 (PWM3)
M4_POT: MOD_4.7, POTS.6 (CHAN3)
M4_X: MOD_4.6, X.6 (CHAN3)
M4_Y: MOD_4.5, Y.6 (CHAN3)
M5_BTN: BUTTONS.5 (CHAN4), MOD_5.4
M5_LED1: BLUE_DRIVER.10 (PWM4), MOD_5.2
M5_LED2: MOD_5.3, ORANGE_DRIVER.10 (PWM4)
M5_POT: MOD_5.7, POTS.5 (CHAN4)
M5_X: MOD_5.6, X.5 (CHAN4)
M5_Y: MOD_5.5, Y.5 (CHAN4)
M6_BTN: BUTTONS.4 (CHAN5), MOD_6.4
M6_LED1: BLUE_DRIVER.11 (PWM5), MOD_6.2
M6_LED2: MOD_6.3, ORANGE_DRIVER.11 (PWM5)
M6_POT: MOD_6.7, POTS.4 (CHAN5)
M6_X: MOD_6.6, X.4 (CHAN5)
M6_Y: MOD_6.5, Y.4 (CHAN5)
M7_BTN: BUTTONS.3 (CHAN6), MOD_7.4
M7_LED1: BLUE_DRIVER.12 (PWM6), MOD_7.2
M7_LED2: MOD_7.3, ORANGE_DRIVER.12 (PWM6)
M7_POT: MOD_7.7, POTS.3 (CHAN6)
M7_X: MOD_7.6, X.3 (CHAN6)
M7_Y: MOD_7.5, Y.3 (CHAN6)
M8_BTN: BUTTONS.2 (CHAN7), MOD_8.4
M8_LED1: BLUE_DRIVER.13 (PWM7), MOD_8.2
M8_LED2: MOD_8.3, ORANGE_DRIVER.13 (PWM7)
M8_POT: MOD_8.7, POTS.2 (CHAN7)
M8_X: MOD_8.6, X.2 (CHAN7)
M8_Y: MOD_8.5, Y.2 (CHAN7)
M9_BTN: BUTTONS.23 (CHAN8), MOD_9.4
M9_LED1: BLUE_DRIVER.15 (PWM8), MOD_9.2
M9_LED2: MOD_9.3, ORANGE_DRIVER.15 (PWM8)
M9_POT: MOD_9.7, POTS.23 (CHAN8)
M9_X: MOD_9.6, X.23 (CHAN8)
M9_Y: MOD_9.5, Y.23 (CHAN8)
M10_BTN: BUTTONS.22 (CHAN9), MOD_10.4
M10_LED1: BLUE_DRIVER.16 (PWM9), MOD_10.2
M10_LED2: MOD_10.3, ORANGE_DRIVER.16 (PWM9)
M10_POT: MOD_10.7, POTS.22 (CHAN9)
M10_X: MOD_10.6, X.22 (CHAN9)
M10_Y: MOD_10.5, Y.22 (CHAN9)
M11_BTN: BUTTONS.21 (CHAN10), MOD_11.4
M11_LED1: BLUE_DRIVER.17 (PWM10), MOD_11.2
M11_LED2: MOD_11.3, ORANGE_DRIVER.17 (PWM10)
M11_POT: MOD_11.7, POTS.21 (CHAN10)
M11_X: MOD_11.6, X.21 (CHAN10)
M11_Y: MOD_11.5, Y.21 (CHAN10)
M12_BTN: BUTTONS.20 (CHAN11), MOD_12.4
M12_LED1: BLUE_DRIVER.18 (PWM11), MOD_12.2
M12_LED2: MOD_12.3, ORANGE_DRIVER.18 (PWM11)
M12_POT: MOD_12.7, POTS.20 (CHAN11)
M12_X: MOD_12.6, X.20 (CHAN11)
M12_Y: MOD_12.5, Y.20 (CHAN11)
M13_BTN: BUTTONS.19 (CHAN12), MOD_13.4
M13_LED1: BLUE_DRIVER.19 (PWM12), MOD_13.2
M13_LED2: MOD_13.3, ORANGE_DRIVER.19 (PWM12)
M13_POT: MOD_13.7, POTS.19 (CHAN12)
M13_X: MOD_13.6, X.19 (CHAN12)
M13_Y: MOD_13.5, Y.19 (CHAN12)
M14_BTN: BUTTONS.18 (CHAN13), MOD_14.4
M14_LED1: BLUE_DRIVER.20 (PWM13), MOD_14.2
M14_LED2: MOD_14.3, ORANGE_DRIVER.20 (PWM13)
M14_POT: MOD_14.7, POTS.18 (CHAN13)
M14_X: MOD_14.6, X.18 (CHAN13)
M14_Y: MOD_14.5, Y.18 (CHAN13)
M15_BTN: BUTTONS.17 (CHAN14), MOD_15.4
M15_LED1: BLUE_DRIVER.21 (PWM14), MOD_15.2
M15_LED2: MOD_15.3, ORANGE_DRIVER.21 (PWM14)
M15_POT: MOD_15.7, POTS.17 (CHAN14)
M15_X: MOD_15.6, X.17 (CHAN14)
M15_Y: MOD_15.5, Y.17 (CHAN14)
M16_BTN: BUTTONS.16 (CHAN15), MOD_16.4
M16_LED1: BLUE_DRIVER.22 (PWM15), MOD_16.2
M16_LED2: MOD_16.3, ORANGE_DRIVER.22 (PWM15)
M16_POT: MOD_16.7, POTS.16 (CHAN15)
M16_X: MOD_16.6, X.16 (CHAN15)
M16_Y: MOD_16.5, Y.16 (CHAN15)
MUX1_S0: POTS.10 (S0), TEENSY++.D7 (7)
MUX1_S1: POTS.11 (S1), TEENSY++.D6 (6,LED)
MUX1_S2: POTS.14 (S2), TEENSY++.D5 (5)
MUX1_S3: POTS.13 (S3), TEENSY++.D4 (4)
MUX1_SIG: POTS.1 (COM), TEENSY++.F1 (39,A1)
MUX2_S0: TEENSY++.C1 (11), X.10 (S0)
MUX2_S1: TEENSY++.C0 (10), X.11 (S1)
MUX2_S2: TEENSY++.E1 (9), X.14 (S2)
MUX2_S3: TEENSY++.E0 (8), X.13 (S3)
MUX2_SIG: TEENSY++.F2 (40,A2), X.1 (COM)
MUX3_S0: TEENSY++.C5 (15,PWM), Y.10 (S0)
MUX3_S1: TEENSY++.C4 (14,PWM), Y.11 (S1)
MUX3_S2: TEENSY++.C3 (13), Y.14 (S2)
MUX3_S3: TEENSY++.C2 (12), Y.13 (S3)
MUX3_SIG: TEENSY++.F3 (41,A3), Y.1 (COM)
MUX4_S0: BUTTONS.10 (S0), TEENSY++.B3 (23)
MUX4_S1: BUTTONS.11 (S1), TEENSY++.B2 (22)
MUX4_S2: BUTTONS.14 (S2), TEENSY++.B1 (21)
MUX4_S3: BUTTONS.13 (S3), TEENSY++.B0 (20)
MUX4_SIG: BUTTONS.1 (COM), TEENSY++.F4 (42,A4)
unnamed: LED1.C, R12.1
OE: BLUE_DRIVER.23 (#OE), ORANGE_DRIVER.23 (#OE), R9.1, R35.1
O_A0: ORANGE_DRIVER.1 (A0), R34.2, SJ_A6.2
O_A1: ORANGE_DRIVER.2 (A1), R33.2, SJ_A7.2
O_A2: ORANGE_DRIVER.3 (A2), R32.2, SJ_A8.2
O_A3: ORANGE_DRIVER.4 (A3), R31.2, SJ_A9.2
O_A4: ORANGE_DRIVER.5 (A4), R30.2, SJ_A10.2
O_A5: ORANGE_DRIVER.24 (A5), R29.2, SJ_A11.2
PWRIN: J2.PWR, Q1.3 (D)
SCL: BLUE_DRIVER.26 (SCL), I2C.2, ORANGE_DRIVER.26 (SCL), R1.P$1 (1), R11.1, R37.1, TEENSY++.D0 (0,PWM,INT0)
SDA: BLUE_DRIVER.27 (SDA), I2C.1, ORANGE_DRIVER.27 (SDA), R2.P$2 (2), R10.1, R36.1, TEENSY++.D1 (1,PWM,INT1)
VCC: TEENSY++.5V (VCC)

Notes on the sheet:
Reverse voltage
protection
1 + A5 + A4 + A3 + A2 + A1 +A1 + RW
I2C Address =
Open = 0 / Closed = 1
MODULES
MUXES
ENCODER

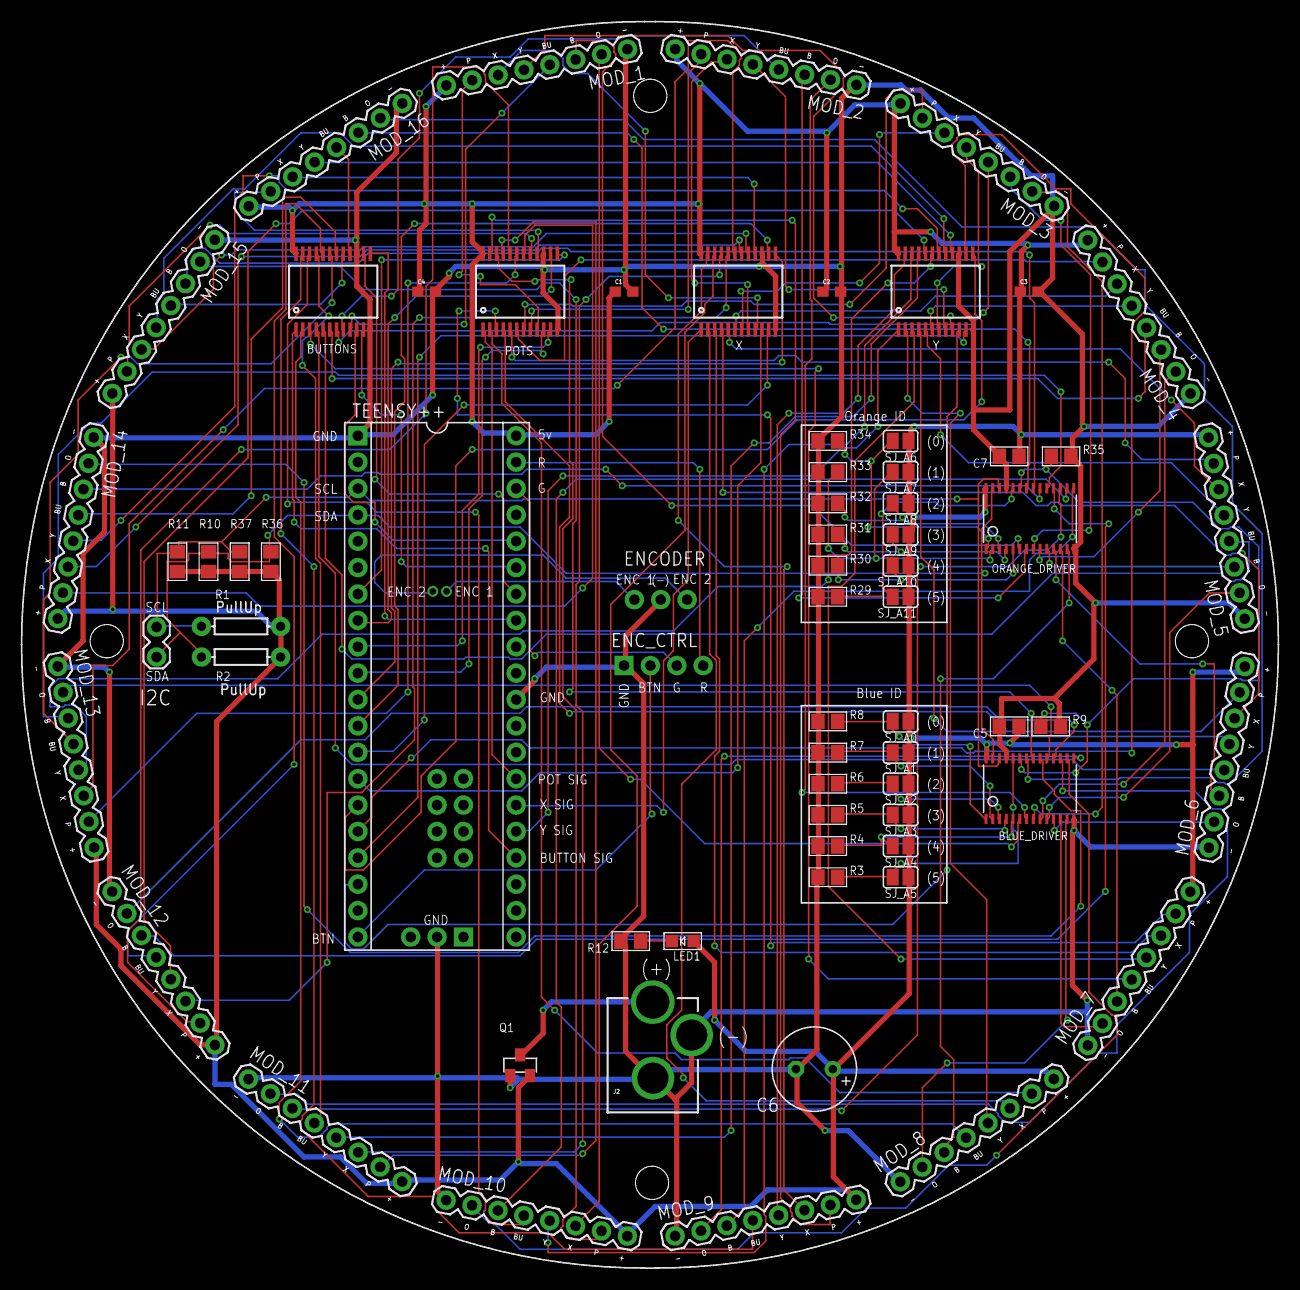
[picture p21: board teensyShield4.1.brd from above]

Board: 2 copper layers, 121.0 x 120.0 mm, 69 parts (0 on the bottom side), 140 nets.

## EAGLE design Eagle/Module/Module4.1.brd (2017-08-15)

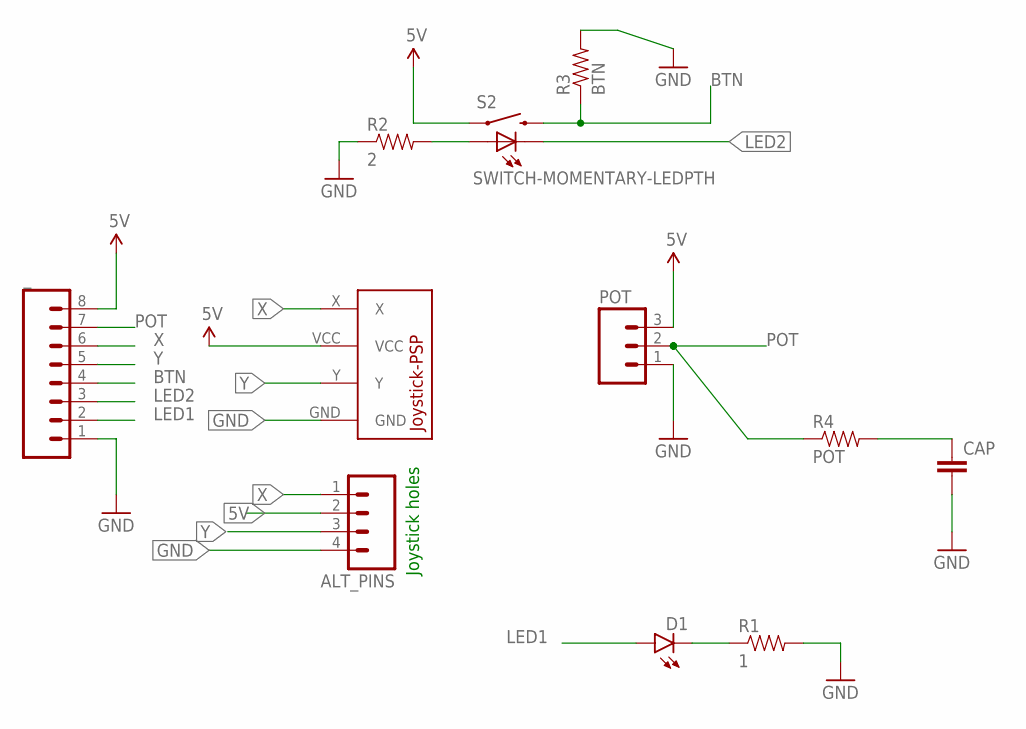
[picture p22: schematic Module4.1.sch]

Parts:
ALT_PINS: M04NO_SILK_ALL_ROUND; 1X04_NO_SILK_ALL_ROUND
CAP: CAPEZ; CAP-PTH-SMALLEZ
D1: LED3MM
POT: M031X03_NO_SILK; 1X03_NO_SILK
R1: 1; AXIAL-0.3-KIT
R2: 2; AXIAL-0.3-KIT
R3: BTN; AXIAL-0.3-KIT
R4: POT; AXIAL-0.3-KIT
S2: SWITCH-MOMENTARY-LEDPTH; TACTILE-PTH-LED-12MM
U$1: JOYSTICK-PSP1000
_: M08; 1X08_ROUND

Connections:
5V: ALT_PINS.2, POT.3, S2.4 (1), U$1.VCC, _.8
BTN: R3.P$1 (1), S2.2, _.4
GND: ALT_PINS.4, CAP.2, POT.1, R1.P$2 (2), R2.P$1 (1), R3.P$2 (2), U$1.GND, _.1
LED1: D1.A, _.2
LED2: S2.C, _.3
unnamed: D1.K (C), R1.P$1 (1)
unnamed: R2.P$2 (2), S2.A
unnamed: CAP.1, R4.P$2 (2)
POT: POT.2, R4.P$1 (1), _.7
X: ALT_PINS.1, U$1.X, _.6
Y: ALT_PINS.3, U$1.Y, _.5

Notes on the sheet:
Joystick holes

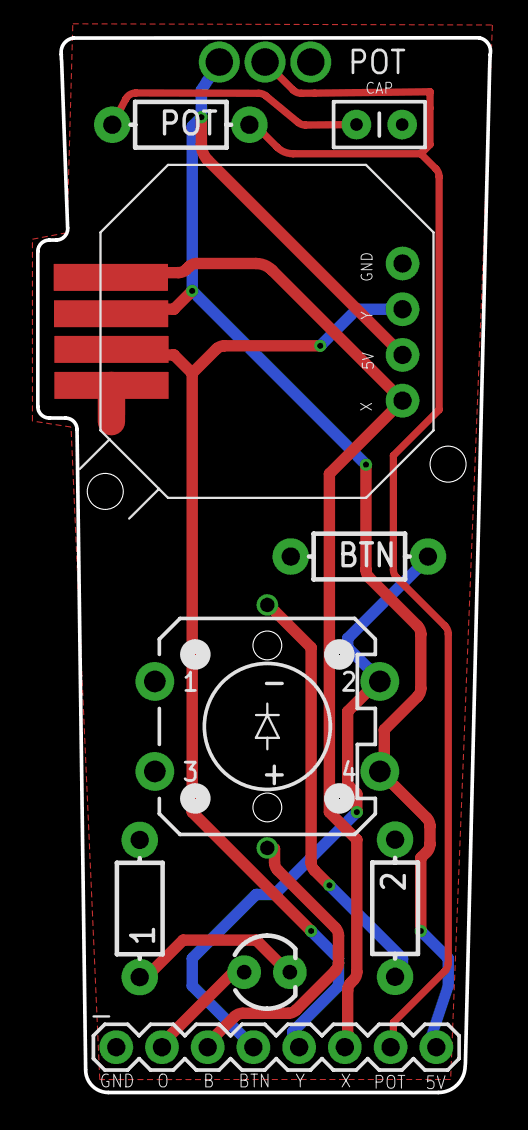
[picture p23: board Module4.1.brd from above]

Board: 2 copper layers, 25.2 x 58.6 mm, 11 parts (0 on the bottom side), 11 nets.

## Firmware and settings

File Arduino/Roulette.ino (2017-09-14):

#include <Mux.h>
#include <Wire.h>
#include <Adafruit_PWMServoDriver.h>


Adafruit_PWMServoDriver orgLED = Adafruit_PWMServoDriver(0x40);
Adafruit_PWMServoDriver bluLED = Adafruit_PWMServoDriver(0x41);

//Mux mux[4] <--NEEDS TO BE THIS, ONCE YOU HAVE PROPERLY CONNECTTED EVERYTHING
/*
  Index of Mux inputs:
  0 - POT
  1 - X
  2 - Y
  3 - BUTTON
*/

//enum muxType {
//  pot,
//  x,
//  y,
//  butt
//  };

Mux mux[4]; // ...or construct now, and call setup later

#define NUM_MODULES 16
#define NUM_BUTTONS 17
#define NUM_LED 16
#define NUM_SLIDERS 3

//Incoming Serial Bytes
char bytes[3];
// constants won't change. They're used here to
// set pin numbers:
//const int buttonPin[] = {7, 6, 5, 4, 3, 2, 15, 14}; // the number of the pushbutton pin

//BUTTONS::
// Variables that will change:
int encButton = 17;
int encLED[] = {26, 25};
int buttonState[NUM_BUTTONS];             // the current reading from the input pin
int ledState[2][NUM_BUTTONS];
int lastButtonState[NUM_BUTTONS];   // the previous reading from the input pin
int reading[NUM_BUTTONS];
unsigned long lastDebounceTime[NUM_BUTTONS];  // the last time the output pin was toggled
unsigned long debounceDelay = 50;    // the debounce time; increase if the output flickers

//PWM FADE
float fadeVal[2][NUM_BUTTONS];
const int pwmInterval = 25;
int pwmIntervals[2][NUM_BUTTONS];
float R;

//POTS::
// for helping with smoothing pot data
const int numReadings = 8;
int potValues[numReadings];


//Mux reading arrays to be populated
int sliders[3][NUM_MODULES];
unsigned long pMillis_Sliders[3][NUM_MODULES];
int currentPotVal[3][NUM_MODULES];
int prevPotVal[3][NUM_MODULES];
int thresh[3][NUM_MODULES];
/*
  [0][16] = pots
  [1][16] = joyX
  [2][16] = joyY
*/
unsigned long interval = 50;

//these pins can not be changed 2/3 are special pins
int encoderPin1 = 36;
int encoderPin2 = 37;
volatile int lastEncoded = 0;
volatile long encoderValue[2];

void setup() {

  // Calculate the R variable (only needs to be done once at setup)
  R = (pwmInterval * log10(2)) / (log10(1023));

  pinMode(encoderPin1, INPUT);
  pinMode(encoderPin2, INPUT);
  //digitalWrite(buttonPin[0], HIGH); //turn pullup resistor on
  digitalWrite(encoderPin1, HIGH); //turn pullup resistor on
  digitalWrite(encoderPin2, HIGH); //turn pullup resistor on
  //call updateEncoder() when any high/low changed seen
  //on interrupt 0 (pin 2), or interrupt 1 (pin 3)
  attachInterrupt(4, updateEncoder, CHANGE);
  attachInterrupt(5, updateEncoder, CHANGE);
  pinMode(encButton, INPUT_PULLUP);

  Serial.begin(115200);
  mux[0].setup(7, 6, 5, 4, A1);
  mux[1].setup(11, 10, 9, 8, A2);
  mux[2].setup(15, 14, 13, 12, A3);
  mux[3].setup(23, 22, 21, 20, A4);

  bluLED.begin();
  orgLED.begin();
  bluLED.setPWMFreq(490);  // Analog servos run at ~60 Hz updates
  orgLED.setPWMFreq(490);

  for (int i = 0; i < NUM_BUTTONS; i++) {
    // pinMode(buttonPin[i], INPUT);
    lastButtonState[i] = LOW;
    lastDebounceTime[i] = 0;
    reading[i] = 0;
    bluLED.setPWM(i, 0, uint16_t(0));
    orgLED.setPWM(i, 0, uint16_t(0));
  }

  yield();
}

void loop() {
  serialRead();
  updateButton();
  updatePot();
  updateLED();
  updateEncLED();
}

//UPDATE::
void updateButton() {
  for (int i = 0; i < NUM_BUTTONS; i++) {
    // read the state of the switch into a local variable:
    if (i == 16) {
      reading[i] = digitalRead(encButton);
    }
    else {
      reading[i] = (mux[3].read(i)) >> 9;
    }
    // check to see if you just pressed the button
    // (i.e. the input went from LOW to HIGH),  and you've waited
    // long enough since the last press to ignore any noise:

    // If the switch changed, due to noise or pressing:
    if (reading[i] != lastButtonState[i]) {
      // reset the debouncing timer
      lastDebounceTime[i] = millis();
    }

    if ((millis() - lastDebounceTime[i]) > debounceDelay) {
      // whatever the reading is at, it's been there for longer
      // than the debounce delay, so take it as the actual current state:

      // if the button state has changed:
      if (reading[i] != buttonState[i]) {
        buttonState[i] = reading[i];
        if (i == 16) serialPrint(3, i, !buttonState[i]);
        else serialPrint(3, i, buttonState[i]);
        if (buttonState[i] == HIGH) {
          ledState[0][i] = !ledState[0][i];
        }
      }
    }
    //PWM FADE
    if (i != 16) fade(0, i, bluLED);

    // save the reading.  Next time through the loop,
    // it'll be the lastButtonState:
    lastButtonState[i] = reading[i];
  }
}

void updateLED() {
  for (int i = 0; i < NUM_BUTTONS; i++) {
    fade(1, i, orgLED);
  }
  //analogWrite(encLED[0], encoderValue[0]);
  //analogWrite(encLED[1], encoderValue[1]);
}
void updateEncLED() {

  if (bytes[0] == 2) {
        analogWrite(encLED[int(bytes[1])], int(bytes[2])); 
  }
}
void fade(int which, int i, Adafruit_PWMServoDriver ledDriver) {
  //This way of fading the LEDs should cause less blocking than a "for loop"
  if (ledState[which][i] == HIGH && fadeVal[which][i] < 1023) pwmIntervals[which][i] += 5;
  else if (ledState[which][i] == LOW && fadeVal[which][i] > 0) pwmIntervals[which][i] -= 5;

  //logarithmic scaling
  fadeVal[which][i] = pow (2, (pwmIntervals[which][i] / R)) - 1;

  ledDriver.setPWM(i, 0, uint16_t(fadeVal[which][i]));
  //pwm1.setPWM(i, 0, uint16_t(fadeVal[i]));

}

void updatePot() {
  // compare value (lowpassed pot reading) to current tempo
  // if value is +- 2 from current tempo then update tempo
  int potVal;
  //Slider array
  for (int i = 0; i < NUM_SLIDERS; i++) {
    for (int j = 0; j < NUM_MODULES; j++) {

      //Read pot, and bitshift it to be in the range of 0 - 127
      //this currently helps with all the noise
      currentPotVal[i][j] = mux[i].read(j) >> 3;
      thresh[i][j] = abs(currentPotVal[i][j] - prevPotVal[i][j]);

      //If timer has past its interval length continue
      if (millis() - pMillis_Sliders[i][j] > interval) {
        pMillis_Sliders[i][j] = millis();

        //If the delta value is large enough print the value
        //this should help decrease noise
        if (thresh[i][j] > 1) {
          //update prevPotVal
          prevPotVal[i][j] = currentPotVal[i][j];
          potVal = prevPotVal[i][j];
          //Store pot value in array
          sliders[i][j] = potVal;
          //Only serial print if data has changed
          serialPrint(i, j, potVal);
        }

      }
    }
  }
}

//SERIAL::
void serialPrint(int section, int member, int data) {
  Serial.print("[");
  Serial.print(section);
  Serial.print(",");
  Serial.print(member);
  Serial.print(",");
  Serial.print(data);
  Serial.println("]");
}

void updateEncoder() {
  int MSB = digitalRead(encoderPin1); //MSB = most significant bit
  int LSB = digitalRead(encoderPin2); //LSB = least significant bit

  int encoded = (MSB << 1) | LSB; //converting the 2 pin value to single number
  int sum  = (lastEncoded << 2) | encoded; //adding it to the previous encoded value

  if (ledState[0][16] == HIGH) {
    if (sum == 0b1101 || sum == 0b0100 || sum == 0b0010 || sum == 0b1011) {
      encoderValue[0] ++;
    }
    if (sum == 0b1110 || sum == 0b0111 || sum == 0b0001 || sum == 0b1000) {
      encoderValue[0] --;
    }
    serialPrint(4, 0, encoderValue[0]);
  }
  else {
    if (sum == 0b1101 || sum == 0b0100 || sum == 0b0010 || sum == 0b1011) {
      encoderValue[1] ++;
    }
    if (sum == 0b1110 || sum == 0b0111 || sum == 0b0001 || sum == 0b1000) {
      encoderValue[1] --;
    }
    serialPrint(4, 1, encoderValue[1]);
  }

  encoderValue[0] = constrain(encoderValue[0], 0, 255);
  encoderValue[1] = constrain(encoderValue[1], 0, 255);

  lastEncoded = encoded; //store this value for next time
}


void serialRead() {
  if (Serial.available() ) {
    if (Serial.read() == 0xff) {
      Serial.readBytes(bytes, 3);
      if (bytes[0] < 2) {
        if (ledState[int(bytes[0])][int(bytes[1])] != int(bytes[2])) {
            ledState[int(bytes[0])][int(bytes[1])] = int(bytes[2]);
         }
      }
    }
  }
}

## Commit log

2017-08-15 added eagle
    [Module1.brd, Module1.sch, Module2.brd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]
2017-08-15 eagle cleanup
    [Module1.brd, Module1.sch, Module2.brd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]
2017-08-15 chuck and CAD
2017-09-14 Arduino added

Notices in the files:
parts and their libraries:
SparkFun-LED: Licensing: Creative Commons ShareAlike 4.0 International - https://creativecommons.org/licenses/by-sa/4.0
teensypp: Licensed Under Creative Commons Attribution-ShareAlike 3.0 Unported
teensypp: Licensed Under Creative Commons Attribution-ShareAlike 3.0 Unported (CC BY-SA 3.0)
